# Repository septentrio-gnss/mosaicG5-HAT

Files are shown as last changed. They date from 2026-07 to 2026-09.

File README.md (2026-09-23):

# mosaicG5 HAT

<p align="center">
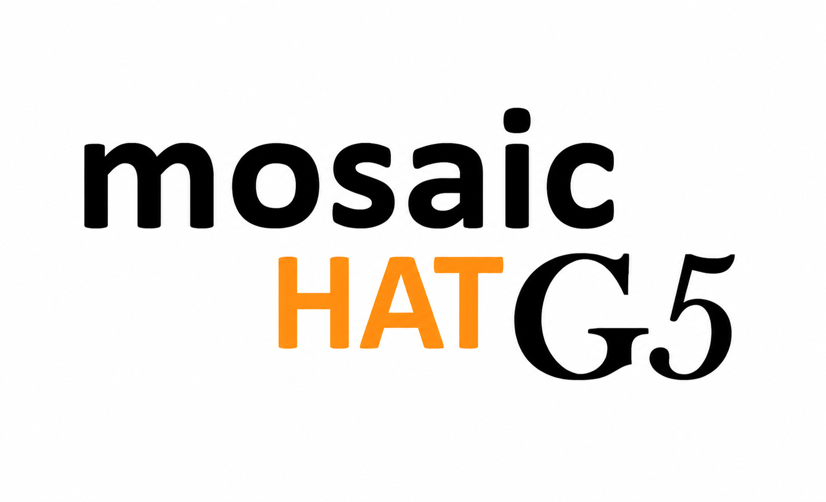
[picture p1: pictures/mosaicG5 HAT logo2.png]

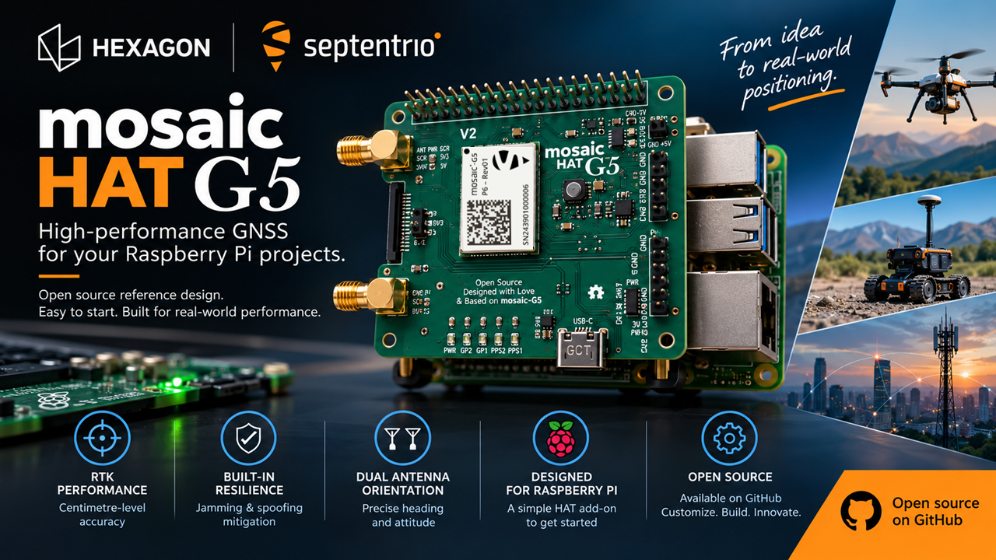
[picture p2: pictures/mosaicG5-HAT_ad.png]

</p>

|mosaicG5 HAT| Open-source GNSS HAT for Raspberry Pi|
|---|---|
|Author|  [laekaz](https://github.com/laekaz)|
|Maintainer| [Septentrio gnss github user](githubuser@septentrio.com)|
|external website| https://github.com/septentrio-gnss/mosaicG5-HAT  |
|License| [CC BY-SA 4.0](https://creativecommons.org/licenses/by-sa/4.0/) and [open-source](https://www.oshwa.org/definition/) |

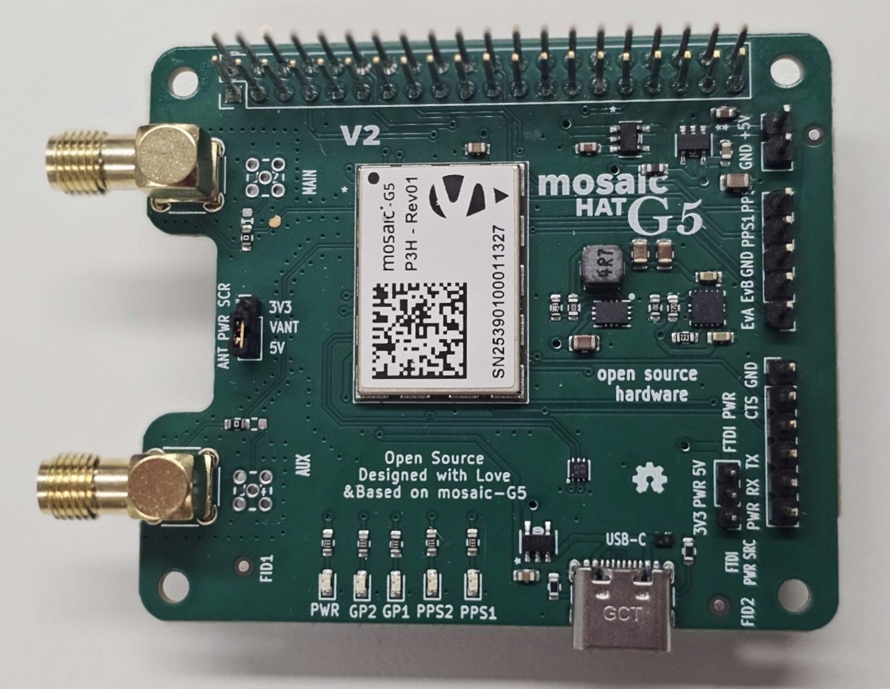
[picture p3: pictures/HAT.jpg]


## Table of Content

* [Introduction to mosaicG5 HAT](#introduction-to-mosaicg5-hat)
  * [What is the mosaicG5 HAT?](#what-is-the-mosaicg5-hat)
  * [A HAT for Raspberry Pi?](#a-hat-for-raspberry-pi)
    * [Robust Mechanical Design](#robust-mechanical-design)
   * [Produce yourself?](#produce-yourself)
    * [Do I need to source special components for producing this board?](#do-i-need-to-source-special-components-for-producing-this-board)
  * [What is a mosaic-G5 module?](#what-is-a-mosaic-g5-module)
    * [Other mosaic-G5 versions](#other-mosaic-g5-versions)
  * [Who is Septentrio?](#who-is-septentrio)
  * [Deliverables](#deliverables)
  * [Is the project open-source?](#is-the-project-open-source)

* [Disclaimer](#disclaimer)

## Introduction to mosaicG5 HAT

### What is the mosaicG5 HAT?
The mosaicG5 HAT is an add-on board that brings high-precision GNSS (GPS) which integrates [mosaic-G5](https://www.septentrio.com/en/products/gnss-receivers/gnss-receiver-modules) Septentrio's GNSS module with basic communications, allowing the system to receive signals from multiple GNSS constellations, such as GPS, Galileo, GLONASS, and BeiDo. 
The goal of the design is to allow easy hardware prototyping and integration of the mosaic-G5 taking advantage of the computer ecosystem provided by the Raspberry pi environment.

The board can also operate as a standalone device when powered through its USB connector or external power input pins.

### Hardware Versions

The mosaicG5 HAT is available in multiple hardware revisions. The latest revision, **V2**, introduces hardware improvements while maintaining compatibility with the software used with V1.

| Version | Description | Software compatibility |
|---|---|---|
| **V1** | Initial production/reference design | Compatible |
| **V2** | Hardware revision with improved hardware design | Compatible |

For detailed information about the changes, advantages, disadvantages, and design decisions of V2, see the [mosaicG5 HAT V2 Hardware Revision](Documentation/mosaicG5%20HAT%20V2%20Hardware%20Revision.md) documentation.

### A HAT for Raspberry Pi?
HAT stands for *Hardware Attached on Top*. It is a type of add-on board specifically designed to sit on top of a Raspberry Pi and connect directly to its 40-pin GPIO header. HATs follow certain standards so they fit neatly, communicate properly, and are powered safely from the Pi.

#### Robust Mechanical Design

Four dedicated mounting holes provide a secure and rigid connection between the Raspberry Pi and the add-on board.

### Produce yourself?
You can use the design files, Bill of Materials from this project and contact your manufacturing company for production. In this project we used JLCPCB for producing the PCB and assembling it. We used JLCPCB because of its competitive pricing and component availability.

##### Do I need to source special components for producing this board?

Yes, Some components are not available through JLCPCB's standard parts library and must be supplied separately. however, if you are assembling the PCB by yourself, all components are available on DigiKey and clearly listed in the project's Bill of Materials. The mosaic GNSS module can be obtained from Digikey or directly from Septentrio. For larger production volumes, we recommend contacting the Septentrio sales team directly at [Septentrio Contact Page](https://www.septentrio.com/en/contact/ask-question)

### What is a mosaic-G5 module?
The mosaic-G5 is a compact GNSS receiver from Septentrio, engineered for high reliability and precise positioning. It integrates the latest multi-band, multi-constellation GNSS technology, providing accurate positions while minimizing power consumption. The receiver can access signals from all major GNSS constellations, including GPS, Galileo, GLONASS, and BeiDou.

#### Other mosaic-G5 versions
Different versions of the mosaic-G5 are available to suit various applications, as summarized below:

| Features | [mosaic-G5 P1](https://www.septentrio.com/en/products/gnss-receivers/gnss-receiver-modules/mosaic-g5-p1) | [mosaic-G5 P3](https://www.septentrio.com/en/products/gnss-receivers/gnss-receiver-modules/mosaic-G5-P3) | [mosaic-G5 P3H](https://www.septentrio.com/en/products/gnss-receivers/gnss-receiver-modules/mosaic-G5-P3H) |[mosaic-G5 P6](https://www.septentrio.com/en/products/gnss-receivers/gnss-receiver-modules/mosaic-G5-P6) | [mosaic-G5 P8](https://www.septentrio.com/en/products/gnss-receivers/gnss-receiver-modules/mosaic-g5-p8) |
|---|---|---|---|---|---|
| Functionality|High-precision positioning |High-precision positioning |Positioning + Heading|Positioning + Heading | Positioning + Heading|
| Use case |Robotics (e.g robotic mowers), GIS devices |UAV, Commercial mowers, Industrial Robotics, Survey, Marine navigation | Marine navigation, Machine control, Autonomous vehicles,  Survey | Autonomous vehicles, Marine navigation, Machine control, Survey | High-end autonomous systems, Robotics, Marine navigation, Survey, Machine control | 
| GNSS bands | Triple-band  | Quad-band | Quad-band |Quad-band |Quad-band  |
| RTK support  | Yes | Yes | Yes |Yes |Yes |
| Dual antenna | No |  No | Yes |Yes |Yes |
| Heading | NO | No | Yes |Yes |Yes |

### Who is Septentrio?
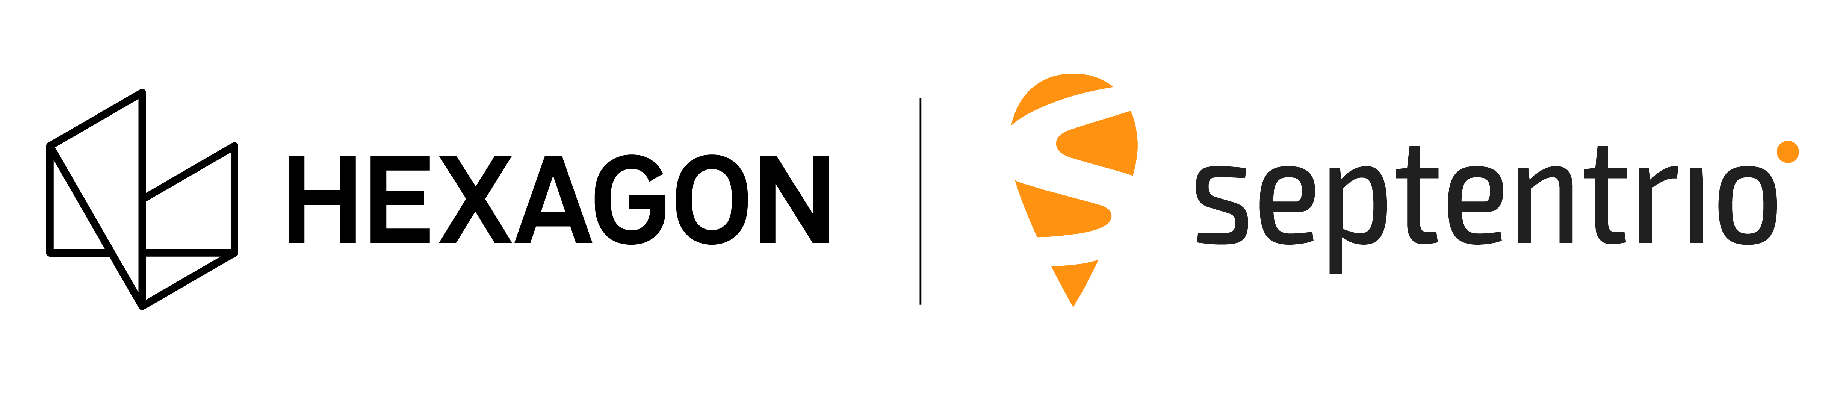
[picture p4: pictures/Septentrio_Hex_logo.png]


Septentrio is a leading company that designs, manufactures and sells high precision and multi-frequency GPS/GNSS receivers for demanding applications. Septentrio products are used in different industries including automotive, marine, construction, rail, machine control, logistics, precision agriculture, geographic information systems (GIS), Unmanned aerial vehicles (UAVs), surveying, mapping and scientific development. Septentrio’s receivers constantly deliver accurate and precise GNSS positioning scalable to centimetre-level and designed to perform perfectly in challenging environments. 

Septentrio's technology offers high accuracy and reliability thanks to advanced GNSS signal-processing algorithms as well as [Advanced interference Monitoring and Mitigation (AIM+)](https://www.septentrio.com/en/learn-more/advanced-positioning-technology/aim-anti-jamming-protection) This protects your application against jamming (RF interference) and spoofing (malicious attacks).

For more information about Septentrio products go to [**https://www.septentrio.com/**](https://web.septentrio.com/GH-SSN-home).

### Deliverables
This project provides the following deliverables for system integrators and hardware designers developing solutions based on Septentrio's mosaic-G5 modules.

|Files |Description |
|---|---|
|  [mosaicG5_RPi_HAT.kicad_pro](./Kicad/mosaicG5%20HAT/V1/mosaicG5_RPi_HAT.kicad_pro) |KiCad project |
| [mosaicG5_RPi_HAT.kicad_pcb](./Kicad/mosaicG5%20HAT/V1/mosaicG5_RPi_HAT.kicad_pcb) | KiCad layout |
|  [mosaicG5_RPi_HAT.kicad_sch](./Kicad/mosaicG5%20HAT/V1/mosaicG5_RPi_HAT.kicad_sch)  |KiCad schematic |
| [mosaic-G5.STEP](./Kicad/mosaci-G5/mosaic-G5.STEP)  |mosaic-G5 3D |
|  [LGA54_MOSAIC-MINI_SEP.kicad_mod](./Kicad/mosaci-G5/LGA54_MOSAIC-MINI_SEP.kicad_mod) |mosaic footprint |
|  [MG5_1.step](./Kicad/mosaicG5%20HAT%203D/MG5_1.step)  |mosaicG5 HAT 3D |
|[BOM](./Kicad/mosaicG5%20HAT/V1/BOM.xlsx) | mosaicG5 HAT Bill of Materials |
### Is the project open-source?
Yes, We made this open-source so you can tinker, adapt, and create. If you are building your own robotics project, a spin-off device, or integrating GNSS into a larger system, this is a great starting point.

Open-source here means:
* All files fully editable
* Freedom to modify, remix, and innovate
* You can sell your version. No -NC limitations
* May require attribution
* Build on our work, push it further, and even make money doing it

More info about licensing can be found here: [CC BY-SA 4.0](https://creativecommons.org/licenses/by-sa/4.0/) and [open-source](https://www.oshwa.org/definition/)

## Disclaimer
This project is **offered as-is**. The main interfaces have been tested, but the design has not been fully checked or approved by the author or Septentrio. You are responsible for how you use it in your own projects. For guidance on working with Septentrio’s GNSS mosaic-G5 modules, we suggest reaching out to Septentrio directly.

Support website: https://www.septentrio.com/en/support
### Documentation Sections

This project provides two main documentation sections:

- **[mosaicG5 HAT User Documentation](Documentation/mosaicG5%20HAT%20User%20Documentation.md)**  
  Contains information for users on how to install, configure, and use the mosaicG5 HAT.

- **[mosaicG5 HAT Design Documentation](Documentation/mosaicG5%20HAT%20Design%20Documentation.md)**  
  Intended for hardware designers who want to understand, customize, or modify the reference design of the mosaicG5 HAT.
- **[mosaicG5 HAT V2 Hardware Revision](Documentation/mosaicG5%20HAT%20V2%20Hardware%20Revision.md)**

  Hardware revision with updated hardware design

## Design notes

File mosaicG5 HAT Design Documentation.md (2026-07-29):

# mosaicG5 HAT Design Documentation

## Table of Content

* [Design Overview](#design-overview)
* [mosaic-G5 Pinout](#mosaic-g5-pinout)
* [Power Sources](#power-sources)
* [Antennas](#antennas)
    * [Antenna Connectors](#antenna-connectors)
    * [First Antenna](#first-antenna)
    * [Second Antenna](#second-antenna)
* [Raspberry Pi Serial](#raspberry-pi-serial)
* [Reset Input](#reset-input)
* [USB-C](#usb-c)
* [Events and PPSO](#events-and-ppso)
* [FTDI](#ftdi)
* [LEDs](#leds)
* [Clock Frequency Reference](#clock-frequency-reference)
* [Further Improvements](#further-improvements)

This section describes the design principles and architecture of the mosaicG5 HAT in depth.

## Design Overview

The mosaicG5 HAT is a four-layer Printed Circuit Board (PCB) designed to mount directly onto a Raspberry Pi. The top and bottom layers are used for both signal and power routing. The first internal layer serves as a ground (GND) plane, while the second internal layer is primarily used as a 3.3 V power plane, with limited routing for additional connections where required.

With the exception of the Raspberry Pi female header connector, all components are mounted on the top side of the board. The design uses Surface-Mount Devices (SMDs) throughout, except for the external connectors.

The mosaicG5 HAT was developed using [KiCad](https://www.kicad.org/download/), an open-source Electronic Design Automation (EDA) suite. In addition to its schematic capture and PCB layout capabilities, KiCad includes an integrated 3D viewer that provides a realistic representation of the assembled board.

The schematic diagram is shown below. For improved readability and access to complete design details, refer to the PDF version of the [schematic](/Kicad/mosaicG5%20HAT/mosaicG5_RPi_HAT.kicad_sch).

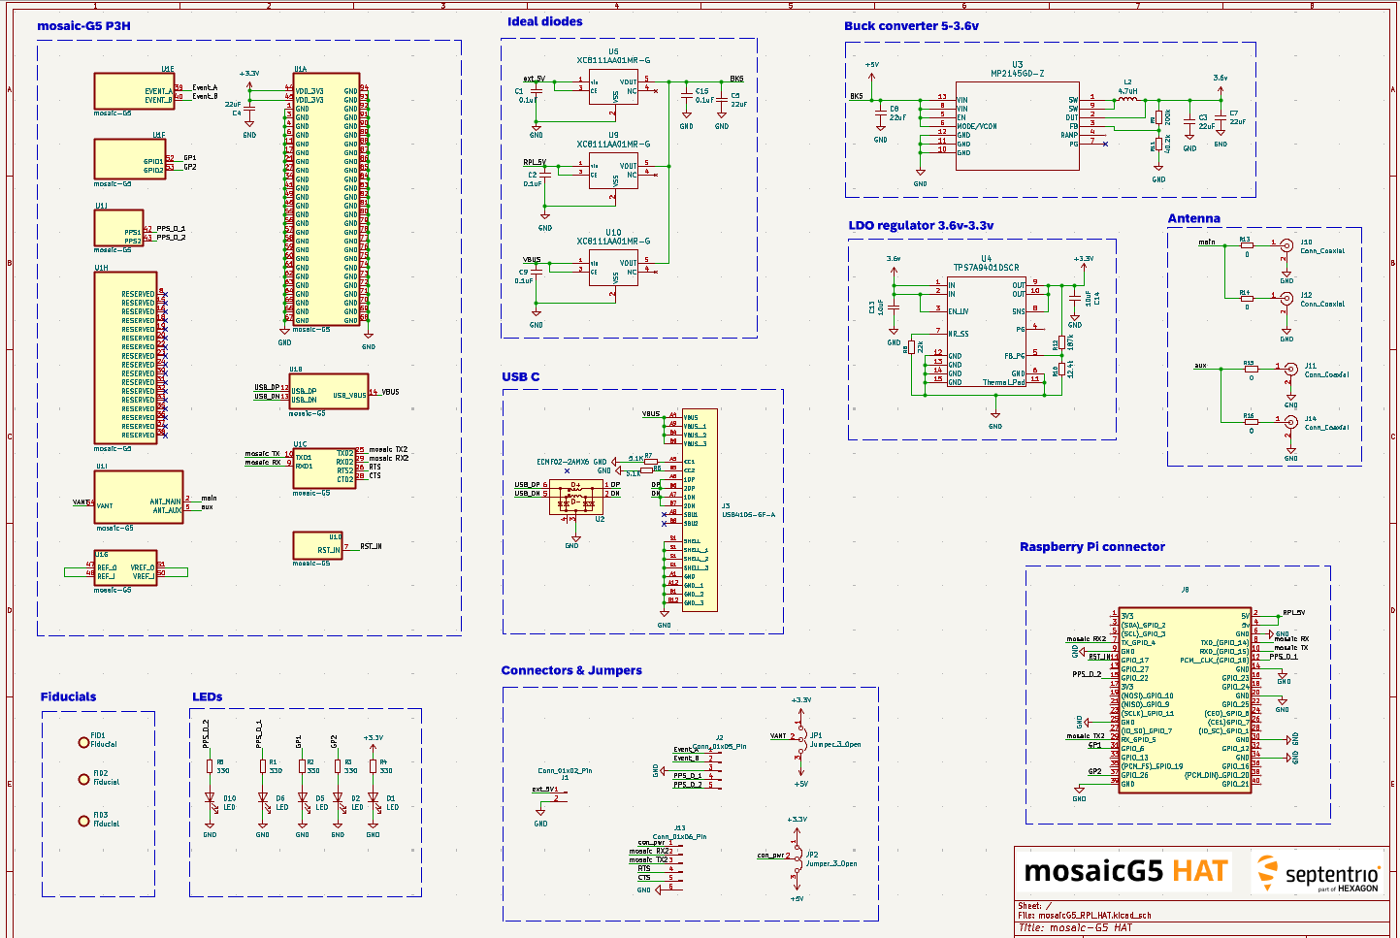
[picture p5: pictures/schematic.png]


The board layout without the copper pour.

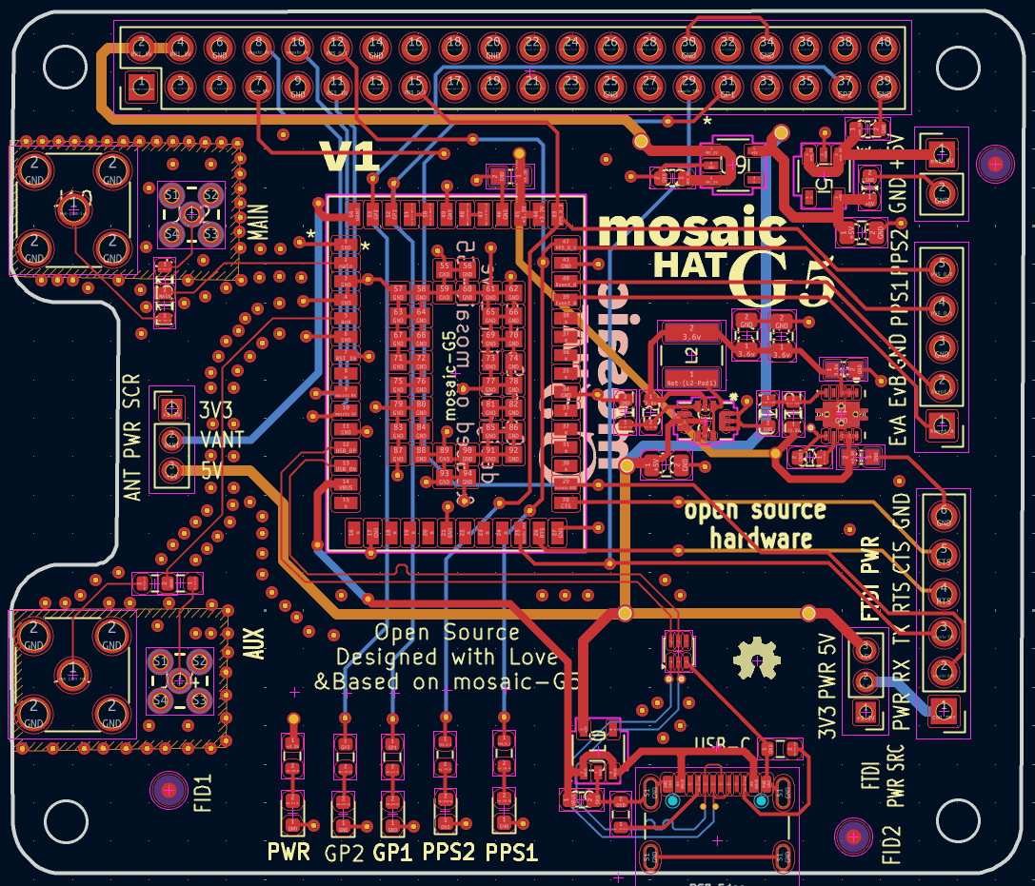
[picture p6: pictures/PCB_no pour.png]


The board layout with the copper pour

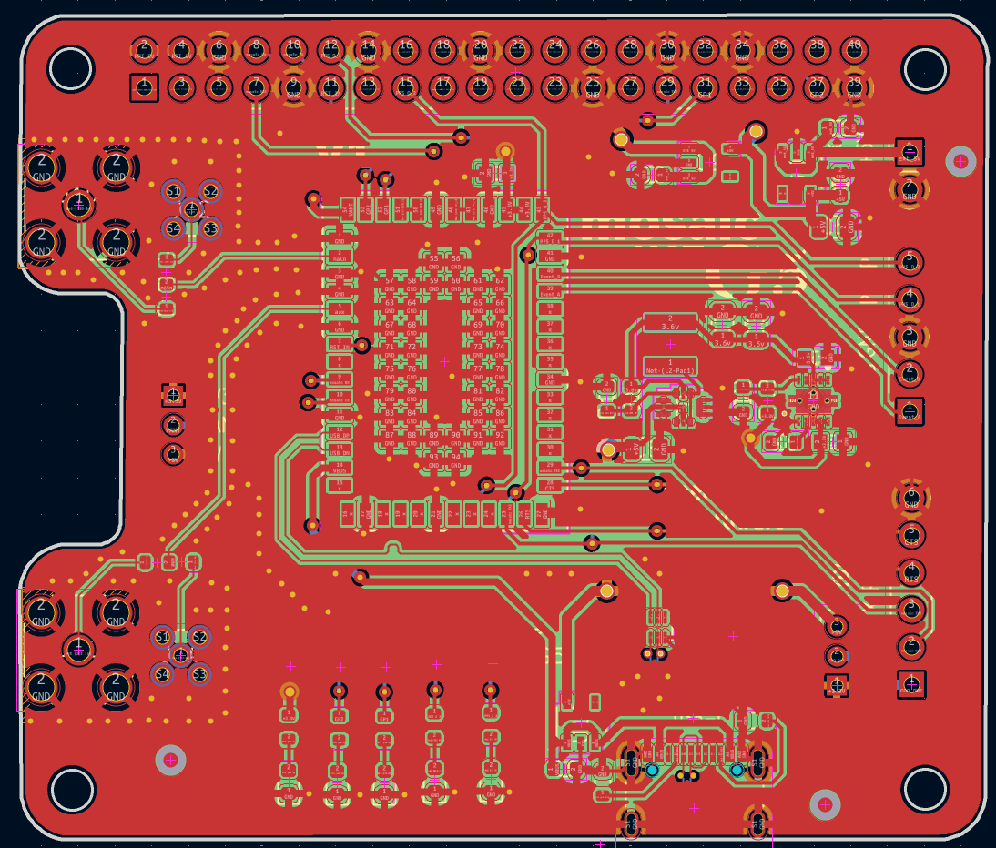
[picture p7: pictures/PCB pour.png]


Layout layer descriptions:

|Layer|Description|
|---|---|
|Layer 1| Red traces, copper pour connected to GND |
|Layer 2| Solid GND plane |
|Layer 3| Orange traces, copper pour connected to 3.3 V |
|Layer 4| Blue traces, copper pour connected to GND|

A top 3D view of the mosaicG5 HAT, featuring main electronic components.

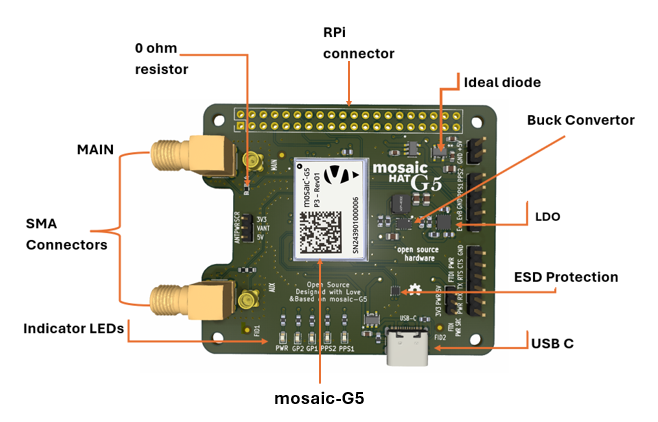
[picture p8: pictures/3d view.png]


## mosaic-G5 Pinout
The Septentrio mosaic-G5 is the core of the mosaicG5 HAT board. It is a 22.8 x 16.4 mm compact GNSS module of 94 pins with a weight of 2.2 g. Complete information on mosaic-G5 connections can be found in the [Hardware Manual](https://www.septentrio.com/en/products/gnss-receivers/gnss-receiver-modules/mosaic-G5-P3H).

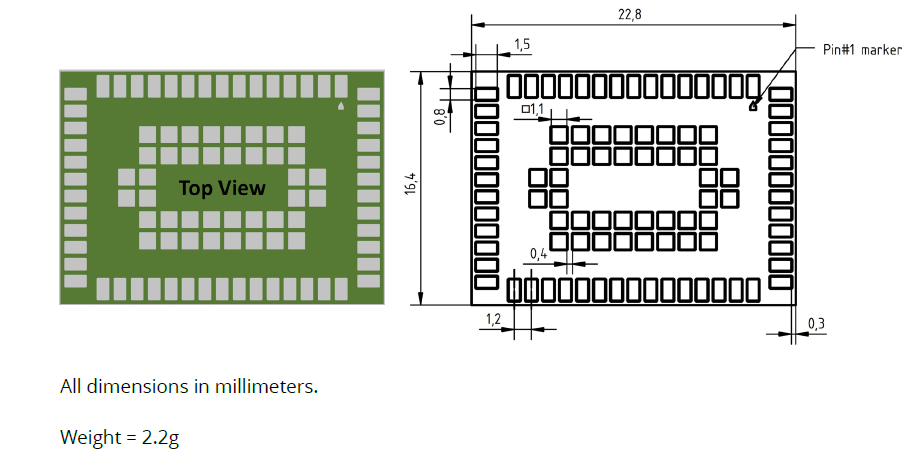
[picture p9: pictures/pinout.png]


The symbol, footprint and 3D model of mosaic-G5 can be found [here](https://app.ultralibrarian.com/details/536b89de-4b22-11f0-b69d-024899f9dfe1/Septentrio/MOSAIC-G5-P3)

## power sources

The mosaicG5 HAT has 3 options for powering the board; Raspberry Pi, USB-C and external power pin headers. The mosaic-G5 module itself runs on 3.3V, thus a buck converter(MP2145GD-Z) is used to regulate the voltage from 5V to 3.6V and an LDO voltage regulator is used to filter the switching noise from the buck converter and to regulate the voltage from 3.7 to 3.3volts(TPS7A9401DSCR). Raspberry Pi and USB-C already provide 5V.

 **NOTE:** When using the external power connector, only 5 V should be applied.

 **WARNING:** Applying voltages higher than 5 V to the external power input or higher than the specified voltage to **VANT** may damage the module

The ideal diodes (**XC8111AA01MR-G**) are used to ensure one-way current flow. Decoupling capacitors (1 µF) are used according to the datasheet. The following figure shows the power section of the schematic.

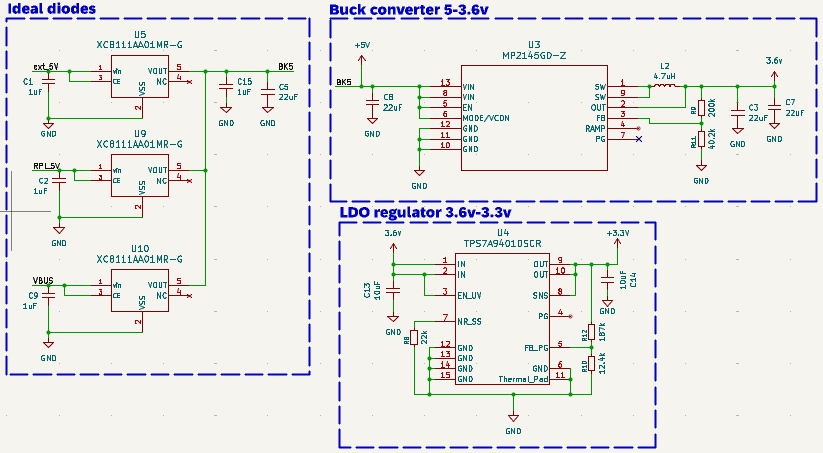
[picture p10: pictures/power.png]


In the figure above:
1. Buck converter(MP2145GD-Z).
2. Voltage regulator (TPS7A9401DSCR).
3. Raspberry Pi power source (5V pins).
4. External power source headers.
5. Micro USB power source.

## Antennas 
The mosaic-G5 P3H is a dual-antenna while the mosaic-G5 P3 is a single-antenna both of these modules are compatible with the PCB board however, when connecting the mosaic-G5 P3 you only connect the main antenna connector and leave the auxiliary unconnected. Both the antenna pins are not ESD-protected or biased in the schematics because all is done inside the module. 

The following figure shows the antenna section of the schematic.

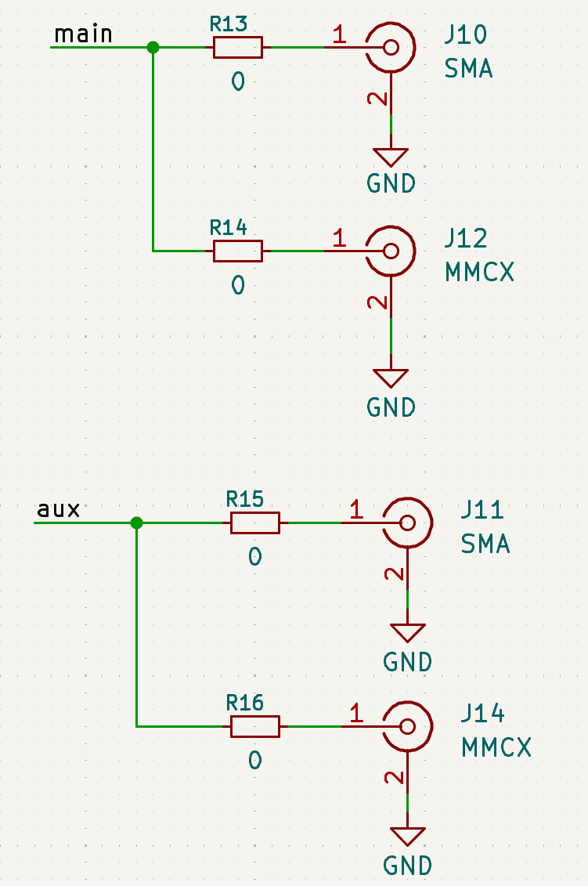
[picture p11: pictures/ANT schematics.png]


### Antenna Connectors

The PCB includes footprints for both SMA and U.FL antenna connectors. When assembling the PCB you can choose the type of connector you are going to choose. You do that by assembling one of the resistor to select either antenna connector.mosaicG5 HAT user can choose between 3.3V and 5V supply for the antenna voltage(VANT) using 2.00 mm header jumpers.

### First Antenna

The first SMA antenna J10 is directly connected to a 0 ohm resistor and the first MMCX antenna J12 is also connected to a 0 ohm resistor and they are both connected to the main mosaic-G5 pin.
The DC voltage of the main antenna connection is supplied from the mosaic-G5's VANT pin.

The input impedance of the RF line is 50 Ohms. Thus, antenna trace should have a characteristic impedance (Zo) of 50 Ohms. To determine the proper impedance for the antenna traces for RF signal routing, calculations were performed with the [JLCPCB Impedance Calculator](https://jlcpcb.com/pcb-impedance-calculator)(recommended if you are using JLCPCB as manufacturer) or can use freeware [Saturn PCB toolkit](https://saturnpcb.com/pcb_toolkit). The trace parameters used in the calculation were based on the specifications of the selected PCB manufacturer. Calculations determined that a trace width of 0.1425 mm would provide an impedance of 50Ω to the RF antenna traces.

Having right characteristic impedance ensures reduced signal reflections in the opposite direction thus higher quality of signals. For uniform lines, characteristic impedance is dependent on trace length.

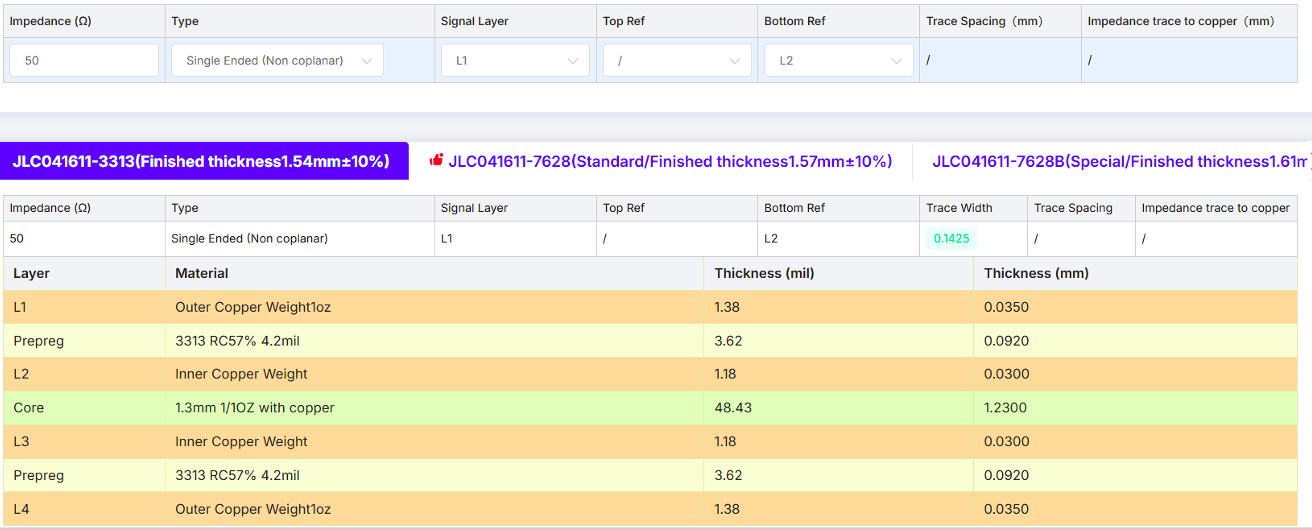
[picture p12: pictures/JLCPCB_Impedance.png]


It is also important to stitch vias every few millimeters around the RF line for good ground coherence. Ground stitching vias help to protect line from interference.

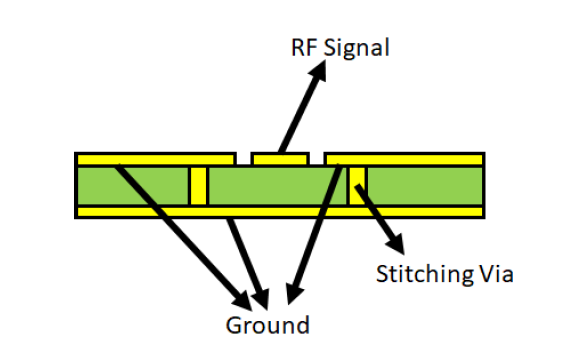
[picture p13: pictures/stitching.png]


For more details on antennas and interference please refer to mosaic-G5's [Hardware Manual](https://www.septentrio.com/en/products/gnss-receivers?f%5B0%5D=type%3A604).

### second antenna

The second antenna is similar to the first antenna except when using a single antenna module like the mosaic-G5 P3, you do not need to assemble the the second antenna connector. 

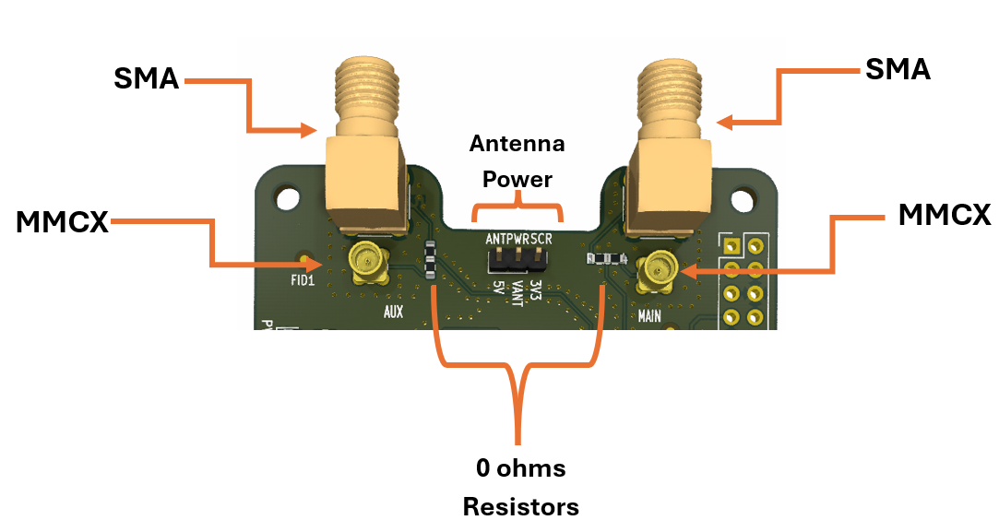
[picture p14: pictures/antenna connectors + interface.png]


## Raspberry pi serial

Serial communication between the mosaic-G5 and the Raspberry Pi is implemented by connecting UART1 and UART2 connections of mosaic-G5 to Raspberry Pi UART pins: TX (GPIO_14, GPIO_5) and RX (GPIO_15, GPIO_4). GPIO_14 and GPIO_5 are pin 8 and pin 29 respectively on the GPIO header whereas GPIO_15 and GPIO_4 are pin 10 and pin 7 respectively. The mosaic-G5's TX is connected to the Raspberry Pi's RX while RX is connected to Raspberry Pi's TX for both UARTs.

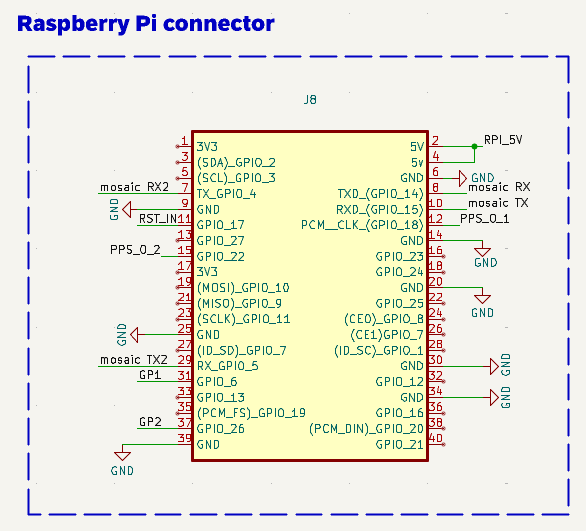
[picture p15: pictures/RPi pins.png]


## Reset Input
The RST_IN pin of mosaic-G5 is directly connected to RPi GPIO 17 (Pin 11 in physical header). Refer to [Reset mosaic](#reset-mosaic-G5) in user documentation for more details.

## USB-C
To use mosaic-G5 as a USB device, the following pins of the module should be connected to a USB-C connector:



A common mode filter with ESD protection for USB 2.0 (ECMF02-2AMX6) is used with USB_DP (D+) and USB_DN (D-) for protection. The filter suppresses electromagnetic interference (EMI) on high-speed differential USB lines.

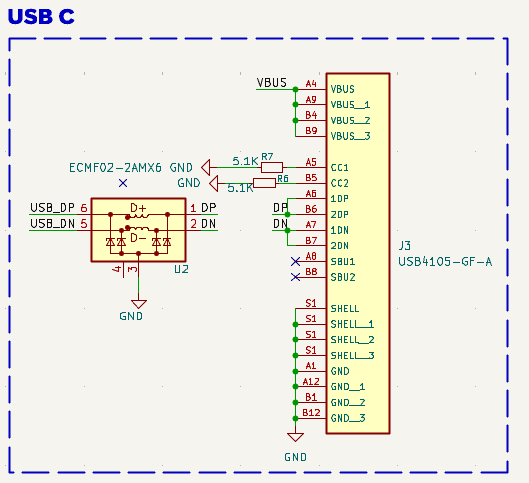
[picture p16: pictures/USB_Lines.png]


As USB uses a differential pair for data transmission, differential pair impedance (Zdifferential) should be tuned to avoid reflections. Zdifferential needs to be around 90 Ohms. The same [JLCPCB impedance calculator](https://jlcpcb.com/pcb-impedance-calculator) was used to determine the dimensions of the differential signal pair that will carry the USB signals. 

The parameters used for this calculation were the same as those used for the RF antenna traces: the materials, thickness of copper finish, and number of layers of the PCB manufacturer that was selected. The results of this calculation determined that a width of 0.1468 mm would provide the necessary impedance of 90 Ω to the differential signal pair. 

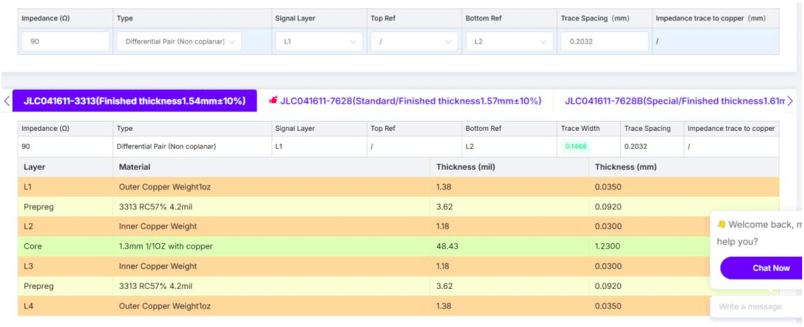
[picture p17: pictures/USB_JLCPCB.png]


The following figure hights USB parts highlighted. GND vias were stitched around the USB connector and lines to ensure good ground coherence.

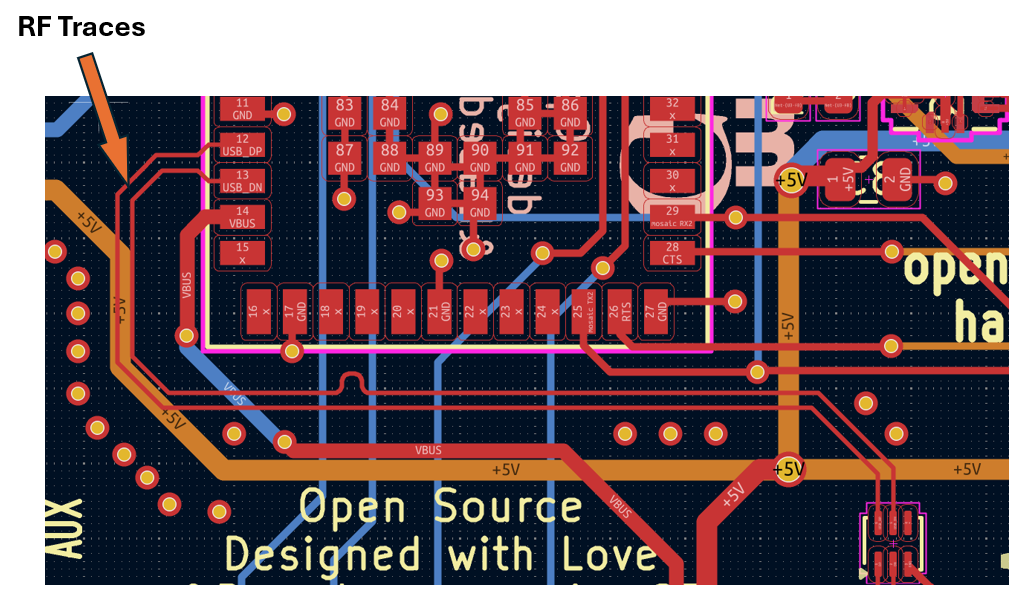
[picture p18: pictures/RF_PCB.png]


* USB-C connector (USB4105-GF-A).
* Common mode filter.
* USB D+/D- lines.
* VBUS.

## FTDI
Second serial interface to mosaic-G5 (UART2) is exposed through 2.54 mm pin headers. The FTDI connection allows communication with other devices through serial (e.g. HC-06 Bluetooth module).

If the external device needs power supply from mosaicG5 HAT, like HC-06, VCC pin of FTDI could be used. 5V or 3.3V could be provided by moving the FTDI PWR SRC jumpers.

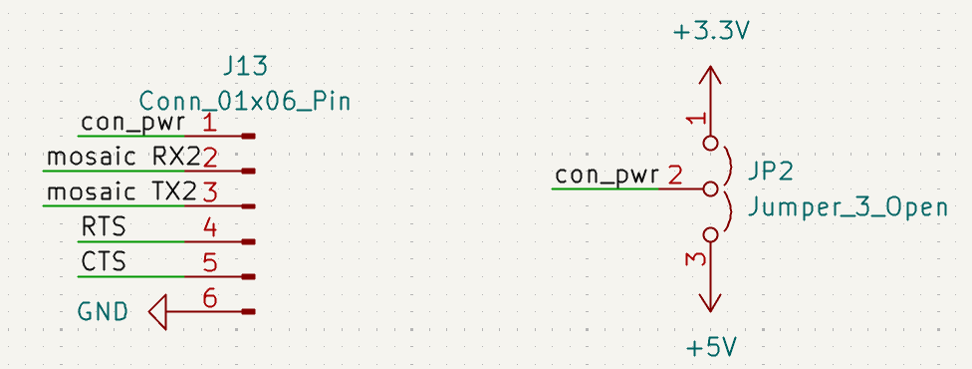
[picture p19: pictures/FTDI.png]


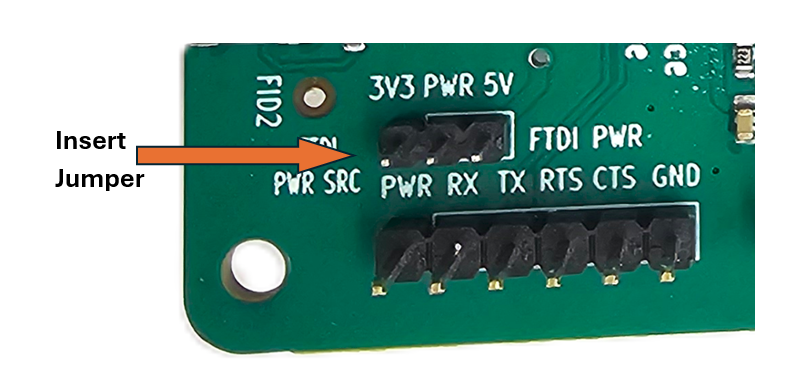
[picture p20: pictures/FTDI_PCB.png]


## LEDs

mosaicG5 HAT has five blue indicator LEDs.

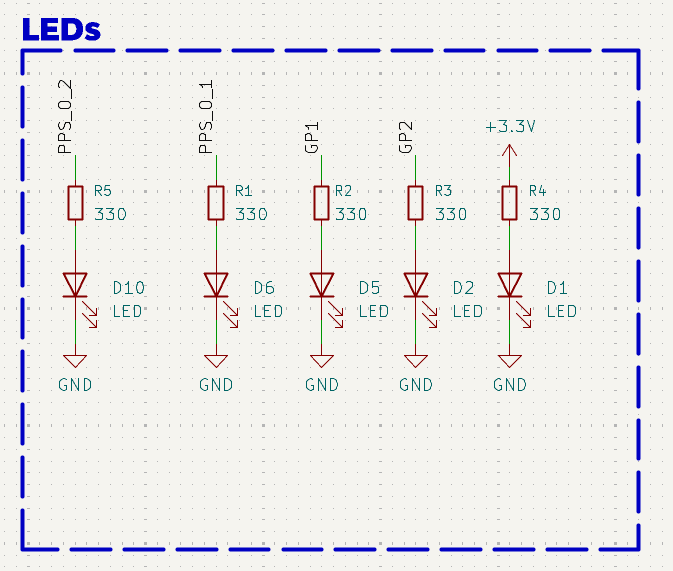
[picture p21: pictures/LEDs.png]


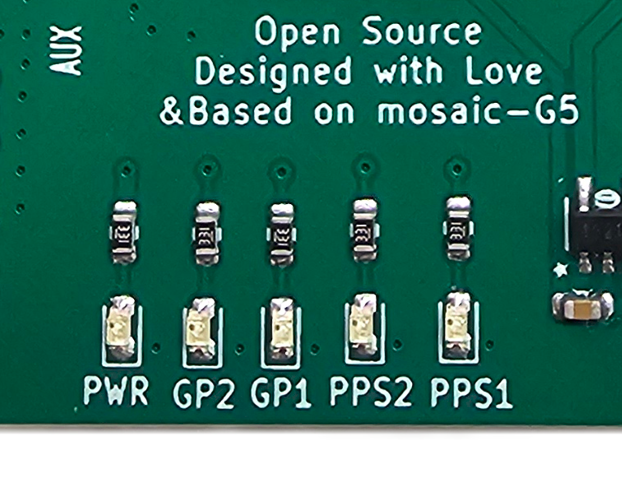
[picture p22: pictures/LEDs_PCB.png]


## Clock Frequency Reference
mosaic-G5 module embeds an internal Temperature Compensated Crystal Oscillator (TCXO) for frequency reference. The module can either use its internal TCXO frequency reference or an external frequency reference. In mosaicG5 HAT's case, internal reference is used.

Following are Hardware Manual instructions for using internal TCXO.



Layout connections for REF and VREF_I.

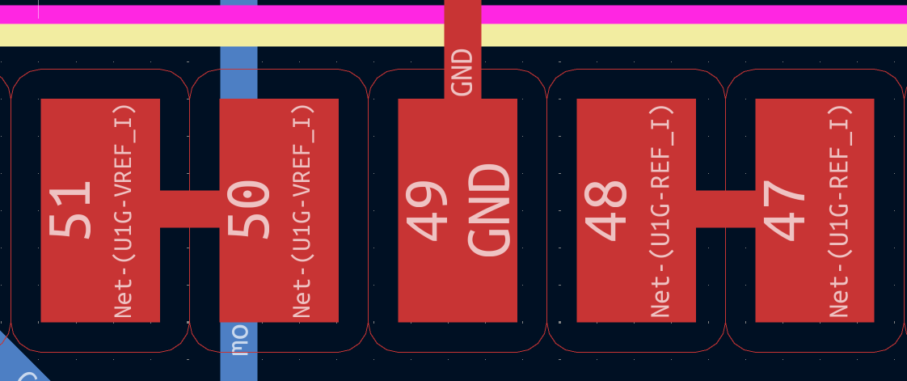
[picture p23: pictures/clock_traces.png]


## Further improvements

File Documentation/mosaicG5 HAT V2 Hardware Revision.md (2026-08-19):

# mosaicG5 HAT V2 Hardware Revision

This document describes the V2 hardware revision of the mosaicG5 HAT and the changes made compared with the original V1 design.

V2 is a hardware-only revision. No changes were made to the software, communication protocol, or user operation of the board.

## Table of Content

## Design Files

| File | Description |
|---|---|
| [mosaicG5_RPi_HAT.kicad_pro](../Kicad/mosaicG5%20HAT/V2/mosaicG5_RPi_HAT.kicad_pro) | V2 KiCad project |
| [mosaicG5_RPi_HAT.kicad_sch](../Kicad/mosaicG5%20HAT/V2/mosaicG5_RPi_HAT.kicad_sch) | V2  KiCad schematic |
| [mosaicG5_RPi_HAT.kicad_pcb](../Kicad/mosaicG5%20HAT/V2/mosaicG5_RPi_HAT.kicad_pcb) | V2  KiCad  PCB layout |
| [BOM](../Kicad/mosaicG5%20HAT/V2/BOM%20P3H_V2.xlsx) | mosaicG5 HAT V2 Bill of Materials |

## V2 Hardware Changes

| Change | V2 modification | Purpose |
|---|---|---|
| **ESD protection** | Added an ESD protection diode on the VBUS input | Protects the board against electrostatic discharge through the USB power connection |
| **Power filtering** | Added **L1 ferrite bead** between the ideal-diode stage and buck converter |Helps filter noise before it reaches the buck converter|
| **FTDI interface** | Rearranged the FTDI pins to follow the standard pin arrangement | Makes the interface more convenient and compatible with standard FTDI connections |
| **Buck converter output** | Increased from **3.6 V to 3.7 V** | Provides additional voltage headroom for the 3.3 V LDO |
| **LDO input margin** | Changed from **3.6 V - 3.3 V** to **3.7 V - 3.3 V** | Increases the voltage margin available to the LDO to maintain a stable 3.3 V output |

### FTDI Interface
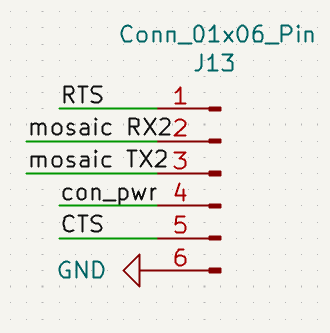
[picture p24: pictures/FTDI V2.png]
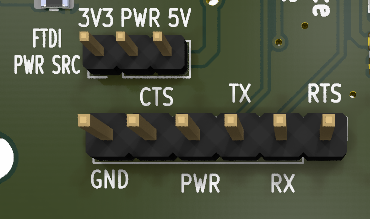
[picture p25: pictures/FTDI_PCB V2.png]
 

The FTDI pin arrangement was changed to follow the standard FTDI pinout, making it easier to connect compatible FTDI cables and adapters while maintaining the same UART2 functionality described in the V1 FTDI section.

### What Remains Unchanged?

No changes were made to:

- mosaic-G5 module
- Raspberry Pi interface
- UART functionality
- PPS functionality
- USB data interface
- Antenna connections
- LED functionality
- Clock reference

These parts of the design remain as described in the V1 documentation.

### Does V2 still work with the existing user documentation?

Yes, V2 remains compatible with the existing mosaicG5 HAT V1 user documentation, with no software changes required, as the communication interfaces and board functionality remain unchanged.

## Revision Summary

| Revision | Description |
|---|---|
| V1 | Initial hardware design |
| V2 | Hardware revision with improved design |

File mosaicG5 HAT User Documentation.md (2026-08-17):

# mosaicG5 HAT user documentation
## Table of Content

* [mosaicG5 HAT User Documentation](#mosaicg5-hat-user-documentation)
  * [mosaicG5 HAT Manufacturing and Assembly](#mosaicg5-hat-manufacturing-and-assembly)
    * [Elements to provide when manufacturing the board](#elements-to-provide-when-manufacturing-the-board)
    * [Ordering mosaic module](#ordering-mosaic-module)
  * [General Interfaces of mosaicHAT](#general-interfaces-of-mosaichat)
  * [Connecting to Raspberry Pi](#connecting-to-raspberry-pi)
    * [Preparing Raspberry Pi](#preparing-raspberry-pi)
  * [GNSS Antenna](#gnss-antenna)
    * [Heading](#heading)
  * [USB Communication](#usb-communication)
  * [Serial Communication](#serial-communication)
  * [FTDI Connector](#ftdi-connector)
  * [LED Indicators](#led-indicators)
  * [Reset mosaic-G5](#reset-mosaic-g5)
  * [PPS Output](#pps-output)
  * [Events](#events)
  * [Python Script](#python-script)

## mosaicG5 HAT Manufacturing and Assembly

This project includes all the files required to manufacture the mosaicG5 HAT, including the reference design, PCB layout, and Bill of Materials (BOM). You can use these files with your preferred PCB manufacturer. For this project, we used [JLCPCB](https://jlcpcb.com/) for both PCB fabrication and assembly due to their competitive pricing and fast production times.

### Elements to provide when manufacturing the board
When you manufacture your board they will ask you for the following parts:

For the PCB only:
* The PCB design, you will need to export gerber and drill files 

For assembly:

* Bill of Materials (BOM), the list of components used in the project with their reference designators. For this project check [BOM](./BOM.xlsx).
* Component Placement List (CPL), this file contains the exact position of each component on the board (X,Y and rotation). CPL is exported from KiCad however, you need to check with the manufacturer services to ensure the right placement for components.

### Ordering mosaic module
You can order the mosaic-G5 from Digi-Key, or you can contact Septentrio at www.septentrio.com for purchasing inquiries or other mosaic models.

| mosaic-G5 versions | Septentrio | Digi-Key part_number|
|---|---|---|
| mosaic-G5 P1 |[Septentrio_G5-P1](https://www.septentrio.com/en/products/gnss-receivers/gnss-receiver-modules/mosaic-g5-p1) | - |
| mosaic-G5 P3 | [Septentrio_G5-P3](https://www.septentrio.com/en/products/gnss-receivers/gnss-receiver-modules/mosaic-G5-P3) | [410501](https://www.digikey.com/en/products/detail/septentrio-inc/410501/28527327) |
| mosaic-G5 P3H |[Septentrio_G5-P3H](https://www.septentrio.com/en/products/gnss-receivers/gnss-receiver-modules/mosaic-G5-P3H) | [410502](https://www.digikey.com/en/products/detail/septentrio-inc/410502/28527213) |
| mosaic-G5 P6 |[Septentrio_G5-P6](https://www.septentrio.com/en/products/gnss-receivers/gnss-receiver-modules/mosaic-G5-P6) | [410503]() |
| mosaic-G5 P8 |[Septentrio_G5-P8](https://www.septentrio.com/en/products/gnss-receivers/gnss-receiver-modules/mosaic-g5-p8) | [410610]() |

## General interfaces of mosaicHAT
The board exposes the following interfaces:

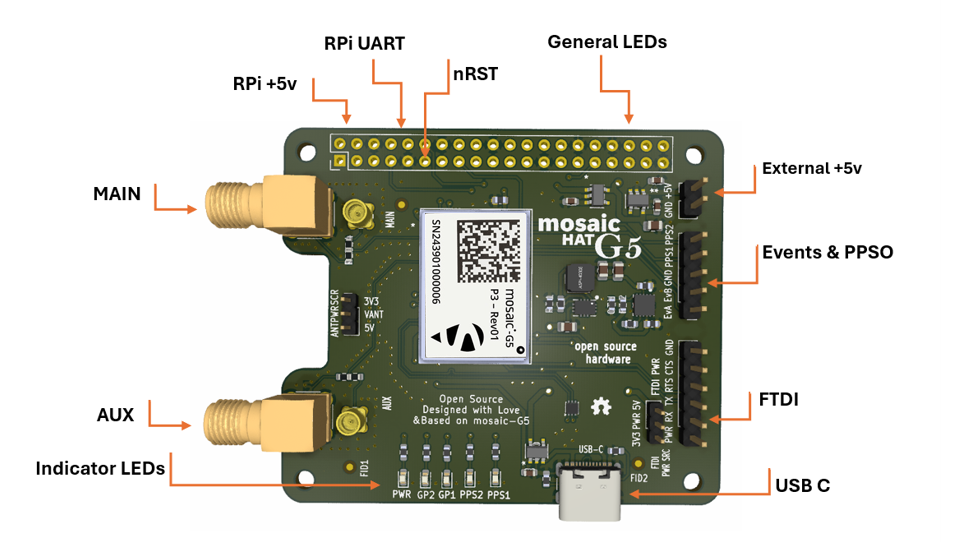
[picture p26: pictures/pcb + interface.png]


## Connecting to Raspberry Pi
mosaicG5 HAT can be easily attached to Raspberry Pi as shown here:

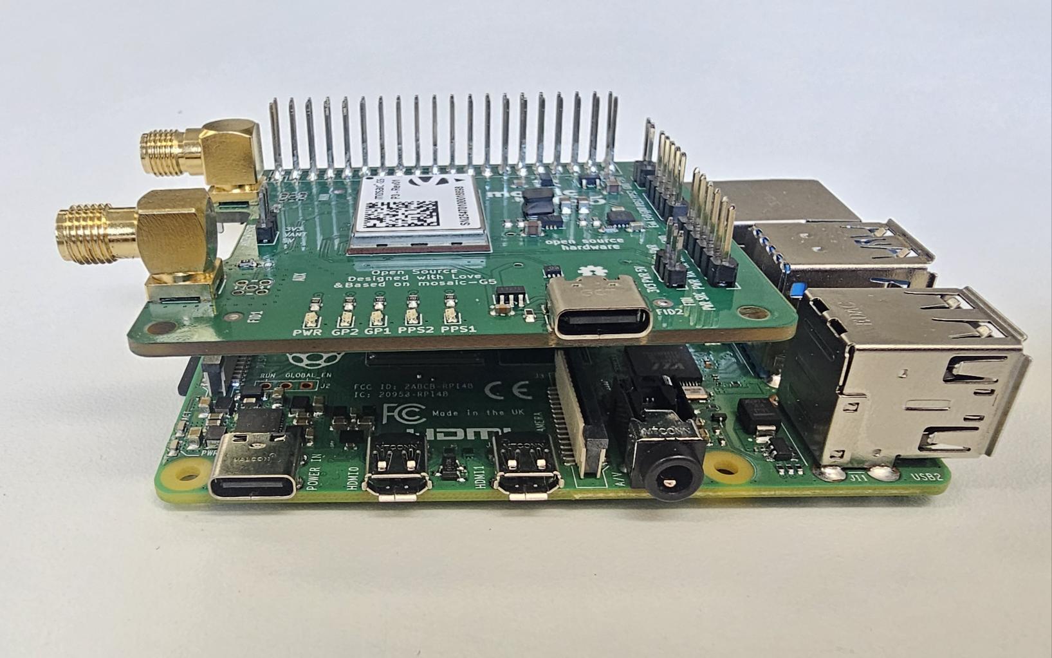
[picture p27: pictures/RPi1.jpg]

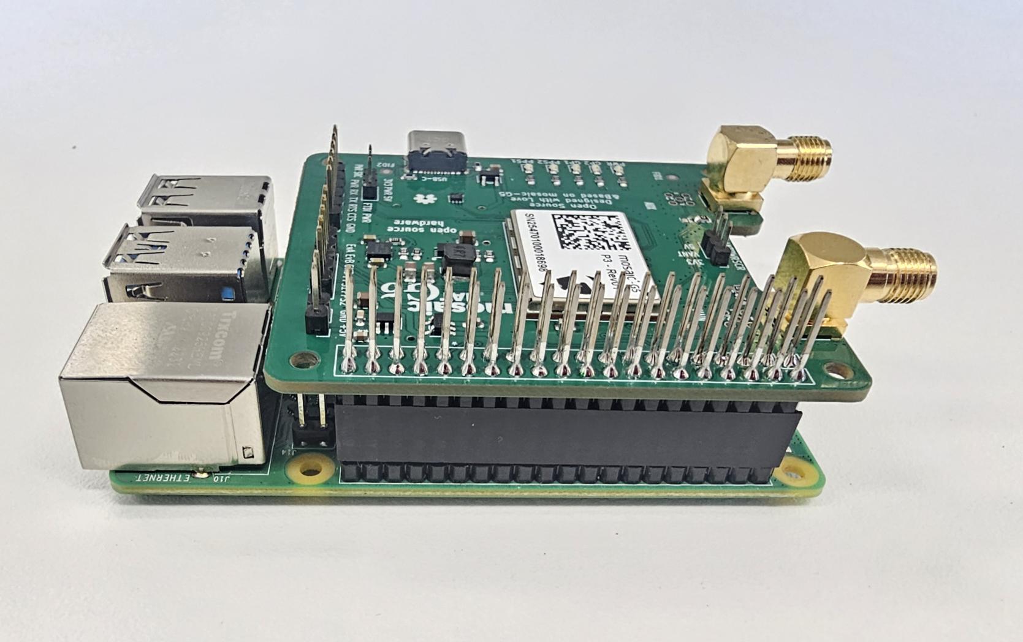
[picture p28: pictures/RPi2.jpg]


### Preparing Raspberry Pi
To enable communication between mosaicG5 HAT and Raspberry Pi (RPi), you should make sure required serial communication settings are configured.

Raspberry Pi OS
* To enable RPi serial communication, go to terminal and run:

```sudo raspi-config```

* Select **Interfacing Options**, then from the menu select Serial Port.
You will get the question:
would you like a login shell to be accessible over serial?
select **No**. Another prompt will ask:
would you like serial port hardware to be enabled?
select **Yes**.

* Reboot the Raspberry Pi for the changes to take effect.

```sudo reboot```

* After reboot check UART devices

```ls -l /dev/serial* ```

The output should be similar to:

```/dev/serial0 -> ttyAMA0```

```/dev/serial1 -> ttyS0```

On the RPi 4 
serial0 maps to GPIO 14 and 15 which are connected to UART1 of the mosaic-G5. 

To communicate with UART1, use:

```/dev/serial0```

To enable RPi's UART, go to /boot/config.txt and set enable_uart=1 at the end of the file. This could be done directly on SD card or using:

```sudo nano /boot/config.txt```

when using the second UART connected from the mosaic-G5 module t the RPi 

add the line ```dtoverlay=uart3``` to the file to enable UART3 connected to the UART2 of the mosaic-G5 module

* Reboot the Raspberry Pi for the changes to take effect.

```sudo reboot```

* After reboot check UART devices

```ls -l /dev/ttyAMA* ```

The output should be similar to:

```/dev/ttyAMA3```

### GNSS Antenna

To take full advantage of the multi-band and multi-constellation capabilities of the mosaicG5 HAT, it is recommended to use a high-quality multi-band GNSS antenna.

Several manufacturers offer suitable GNSS antennas, including Maxtena and Tallysman. You can also contact Septentrio for guidance on selecting an antenna that best fits your application.

GNSS antennas are available in different form factors and performance levels, each designed for specific use cases such as robotics, precision agriculture, surveying, or industrial machinery. While larger antennas often provide better performance due to improved antenna design and larger ground planes, antenna quality and internal element design are equally important factors. Selecting the right antenna for your application will have a significant impact on positioning accuracy and reliability.

For testing the board we used Tallysman antenna:

<img src="pictures/antenna.jpg" width="30%">

**NOTE**: The VANT (Antenna voltage) pad of mosaic-G5 module is directly connected to the external +5V pin. The internal bias control circuit detects overcurrent
conditions (>150mA) and protects the module in case of short circuit. According to mosaic-G5 hardware manual, VANT accepts 3V to 5.5V power supply.

When using the external power supply, make sure it is not more than 5V. Supplying higher voltages to VANT could **DAMAGE** the module.

#### Single/Dual Antenna Mode

The receiver can operate in either **single-antenna** or **dual-antenna** mode. Changing the frontend mode only takes effect after a reboot.

**Single-antenna mode**

Run:

```
setFrontendMode, SingleAnt
```
to configure the receiver for single-antenna mode at the next reboot.

Then save the configuration:

```
exeCopyConfigFile, Current, Boot
```

Finally, reboot the receiver:

```
exeResetReceiver, Hard, none
```

**Dual-antenna mode**
Run:

```
setFrontendMode, DualAnt
```
to configure the receiver for dual-antenna mode at the next reboot.

Then save the configuration:

```
exeCopyConfigFile, Current, Boot
```
Finally, reboot the receiver:

```
exeResetReceiver, Hard, none
```
P3H, P6 and P8 can run both in single or dual mode deppending on how you configure it. connect both the antenner connectors when using dual mode. 

#### Heading

You can use mosaic-G5 P3H for heading but **it's necessary to connect the two antenna connectors.** 

RxTools can be used to monitor the heading.

<img src="pictures/Heading.png" width="50%">

### USB communication

The mosaicG5 HAT via USB provides 2 USB serial ports that can be used with [Septentrio's RxTools](https://www.septentrio.com/en/products/gps-gnss-receiver-software/rxtools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).

Septentrio's RxTools is a Software which can be used to communicate to the mosaic-G5 HAT and can be downloaded free of charge from the [Septentrio support site](https://www.septentrio.com/en/products/gps-gnss-receiver-software/rxtools#resources). Once you have downloaded it you can use Septentrio's RxControl and Data Link which can communicate with the receiver over a serial-port connection: select Serial Connection option when opening the connection to the receiver.

<img src="pictures/rxcontrol.png" width="50%">

**NOTE:** That currently there's no RxTools release for RPi (ARM architecture). Thus, RxTools should be used on a regular PC.

### Serial communication
A simple way to communicate with the mosaic-G5 receiver is to connect one of the UART, it offers 2 UARTs connections.

* Both UART connections are  connected to the Raspberry-Pi for easie integration.

### FTDI-connector
An extra serial port is made available and can be used as an FTDI. FTDI can also be used with some Bluetooth devices. There is a large variety of FTDI devices which can help in communicating with the mosaic G5 HAT.

* The UART2 connection of the mosaic is exposed via pin header on the board. This can be usuable to connect an FTDI converter(eg. serial to Bluetooth or TLL to RS232 converter)

<img src="pictures/FTDI_TTL.png" width="50%">

TTL to USB connection

<img src="pictures/TLL_connection.png" width="50%">

Serial connection of mosaic G5 HAT could be tested using PuTTY

Default COM-Port settings are:
|Parameter     |Value         |
|--------------|--------------|
|baud rate     | 115200     |   
|data bits | 8   |
|parity    |no    |
|stop bits | 1    |
|flow control | none|

<img src="pictures/putty.png" width="50%">

Can use comment ```sno, Stream1, COM2, GGA, sec1``` to output GGA data on the UART2

### LED indicators
The follwing LEDs are defined on the mosaicHAT

|**LED**  |**Description**   |
|-------|-------|
|PWR    | Board State (ON/OFF)  |
|GL1    | Conected to mosaic G5 and RPi GPIO1  |
|GL2 | Connected to mosaic-G5 and RPi GPIO26   |
|PPS2 | Pulse Per Second  |
|PPS1 | Pulse Per Second  |

<img src="pictures/LED_indicators.png" width="50%">

PPSO clock could be tuned using **setPPSParameters** command. While GPLEDs default mode is PVTLED, it could be configured to work in different modes (PVTLED, DIFFCORLED and TRACKLED) using setLEDMode command. Refer to the Hardware Manual for blinking behaviour of each mode. Both General Purpose LEDs (GL1 and GL2) could be directly controlled by Raspberry Pi GPIO.

Just for illustration, the following python script runs GL1 and GL2  together with the GNSS code. When there is no GNSS data GL1 will turn on and when there is GNSS data GL2 will turn on.

Find the code [here](/Python%20code/MG5_RPI_LED_code.py)

### Reset mosaic-G5

mosaic-G5 could be forced to reset from Raspberry Pi. The RST_IN pin of mosaic-G5 is directly connected to RPi GPIO 17 (Pin 11 in physical header).

The RST_IN pin is active negative, which means mosaic will be in RESET mode when RST_IN is low (GND). The pin is internally debounced (pull-up) so if pin is left unconnected (floating) the module will not enter RESET mode.

Initially, the RPi GPIO pins are set to INPUT mode. As the RPi input line have high impedance, RST_IN will be floating. This means mosaicHAT board could run without issues initially even if GPIO 17 is not set to HIGH (while kept in input mode). However, it is not recommended to rely on the GPIO initial state. Users should drive HIGH to GPIO 17 for the stability of their applications.

To reset module, a LOW pulse, not shorter than 1 microsecond, should be driven to GPIO 17.

### PPS output

PPS signals are used for precise timekeeping and time measurement. One increasingly common use is in time synchronization with other sensors (e.g. Lidars or IMUs).

The receiver is able to generate an x-pulse-per-second (xPPS) signal aligned with GPS, Galileo, GLONASS system time, UTC, or with the internal receiver time (RxClock). 

Polarity, frequency and pulse width of PPSO could be configured by **setPPSParameters** command.

<img src="pictures/Eve&PPSO.png" width="50%">

By default, **PPSO2 is disabled**. It can be enabled and configured in **RxControl**:.

<img src="pictures/PPS2.PNG" width="50%">
<img src="pictures/PPS2_.png" width="25%">

Both PPS Output operate at 3.3 V logic levels. PPSO1 and PPSO2 are directly connected to an indicator LED. 

More information on the definition of PPS output or on how to configure the PPS parameters can be found in the mosaic-G5 reference guide. You can download this one from [Septentrio site](https://www.septentrio.com/en/products/gnss-receivers/gnss-receiver-modules/mosaic-G5-P3H).

### Events
EVENTs could be tested directly on mosaicG5 HAT board by connecting PPS Output to one of the EVENTs pins. Note that this works with a single wire because they share the same GND. Here PPSO_1 is connected to EVENTB, with PPS interval set to 1 sec.

<img src="pictures/event_console.png" width="40%">
<img src="pictures/event.png" width="30%">

To monitor Events you could use Rxcontrol, clicking on the expert console. once you have connected an output to the event pin you will see the data being recieved on the pin.

**Note:** The **EVENT** inputs use **3.3 V logic levels**. Applying higher voltages may damage the receiver.

For more information about the EVENT input functionality, see the **mosaic-G5 Reference Guide**, available from the [Septentrio website](https://www.septentrio.com/en/products/gnss-receivers/gnss-receiver-modules/mosaic-G5-P3H).

### Python script

Find the full code [here](/Python%20code/MG5_RPI_code.py)
```
import serial   # Library used for UART / serial communication
import time     # Library used for implementing timing delays

# Establish UART serial connection to the GNSS receiver
serial_port = serial.Serial('/dev/serial0', 115200)

# /dev/serial0 refers to the primary Raspberry Pi UART interface
# 115200 baud is the default communication speed of the mosaic-G5 receiver

# If using USB serial communication instead of UART, the device may appear as:
# /dev/ttyACM0, /dev/ttyACM1, etc.
# Available serial devices can be checked using:
# dmesg | grep tty

# If permission errors occur when accessing USB serial ports, run:
# sudo chmod 666 /dev/ttyACM0

time.sleep(1) # delay for serial connection time to be initialise properly

serial_port.write(b'SSSSSSSSSSSSS\n') # Send multiple 'S' characters to place the mosaic-G5 into command mode

time.sleep(0.1) # Short delay to ensure the command is processed

# Enable continuous NMEA GGA message streaming once per second on COM1
# For USB communication, replace COM1 with USB1 or USB2
serial_port.write(b'sno, Stream1, COM1, GGA, sec1\n')

time.sleep(0.1) # delay for reading incoming serial data

while True:
  
    nmea_data_bytes = serial_port.readline()          # Read one complete line of incoming serial data from the receiver   
    nmea_sentence = str(nmea_data_bytes.decode())      # Decode received byte data into a UTF-8 string    
    nmea_sentence = nmea_sentence.rstrip()            # Remove newline and whitespace characters

    # Check if the received NMEA sentence is a GNGGA position message
    if (nmea_sentence.startswith('$GNGGA')):
       
        nmea_fields = [element.strip() for element in nmea_sentence.split(',')]      #separated NMEA fields with a comma into a list
       
        quality_indicator = int(nmea_fields[6])                                      #Get the NMEA quality indicator field
       
        if quality_indicator==0:                    # Quality indicator value of 0 means no valid GNSS position fix

            print("No GPS Fix Available!")

        else:
            utc_time = float(nmea_fields[1])                 # Parse UTC time field from the NMEA GGA message
            latitude = float(nmea_fields[2])*0.01            # Get latitude value in NMEA format
            latitude_direction = nmea_fields[3]             # Get latitude hemisphere indicator (N or S)
            longitude = float(nmea_fields[4])*0.01           # Get longitude value in NMEA format
            longitude_direction = nmea_fields[5]             # Get longitude hemisphere indicator (E or W)
            altitude = float(nmea_fields[9])                  # Get altitude above mean sea level           
            altitude_unit = nmea_fields[10]                  # Get altitude unit, typically metres (M)

            # Display parsed GNSS positioning information
            print('UTC Time: ' + str(utc_time))
            print(' Latitude: ' + str(latitude) + latitude_direction)
            print(' Longitude: ' + str(longitude) + longitude_direction)
            print(' Height: ' + str(altitude) + altitude_unit)  

        # Delay before processing the next incoming message
        time.sleep(0.1)
    else:
        continue         # Ignore non-GGA NMEA messages and continue listening
serial_port.close()     # Close serial connection when the program terminates

```

When you connect to the second UART change **COM1** to **COM2** o

```serial_port.write(b'sno, Stream1, COM2, GGA, sec1\n')```
and the serial port

```serial_port = serial.Serial('/dev/ttyAMA3', 115200)```

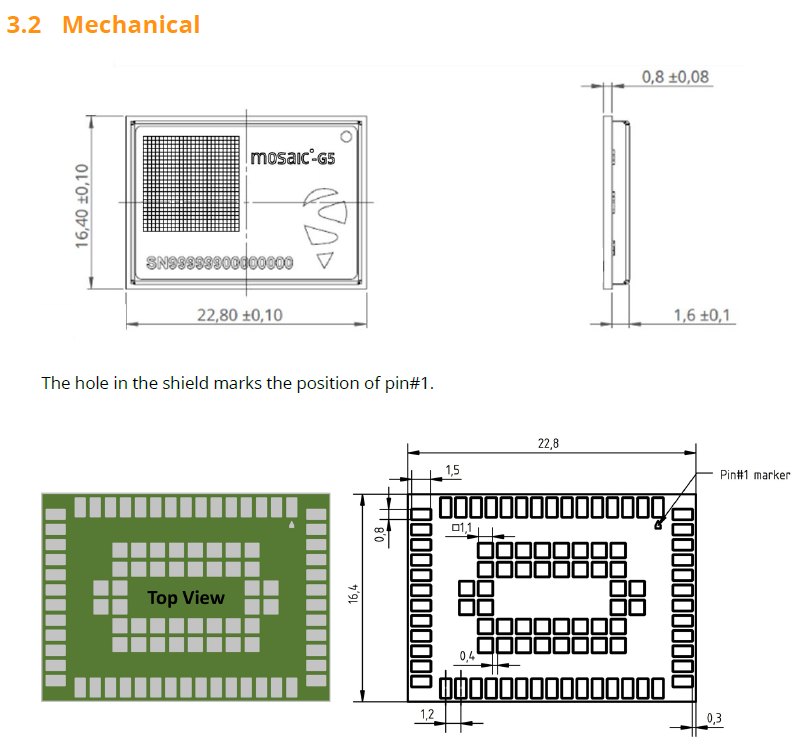
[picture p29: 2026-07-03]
pictures/mechanical.png

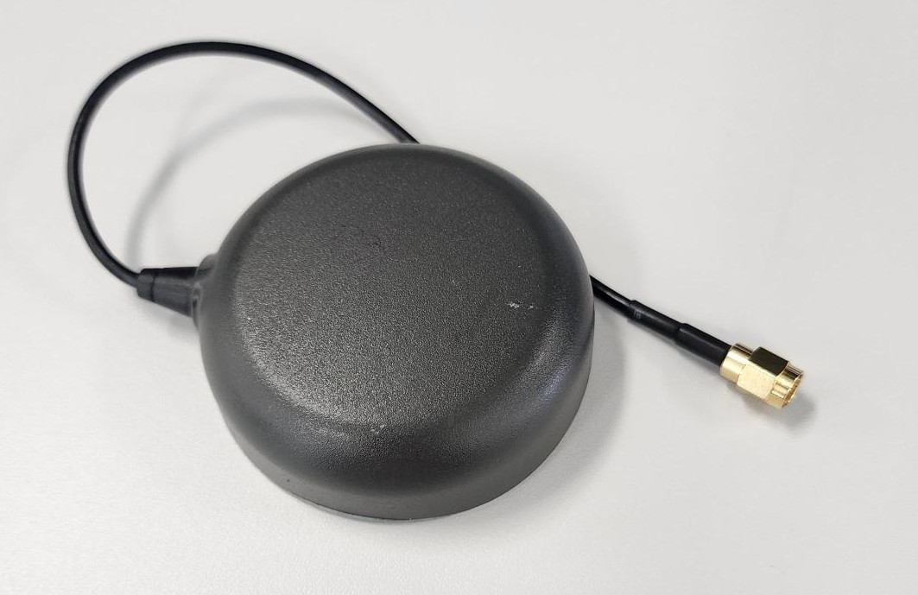
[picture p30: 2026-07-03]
pictures/antenna.jpg

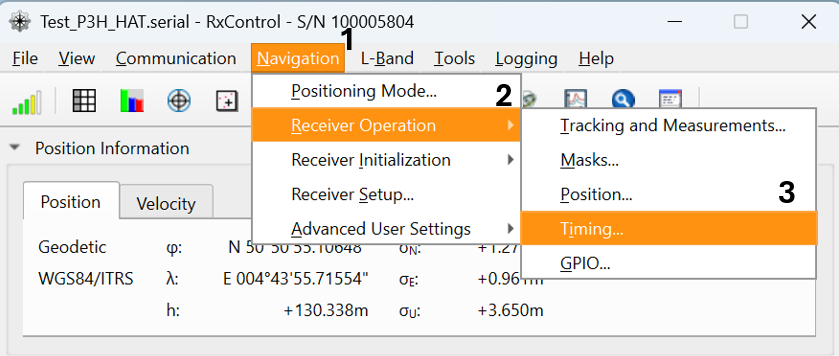
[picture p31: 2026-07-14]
pictures/PPS2.PNG

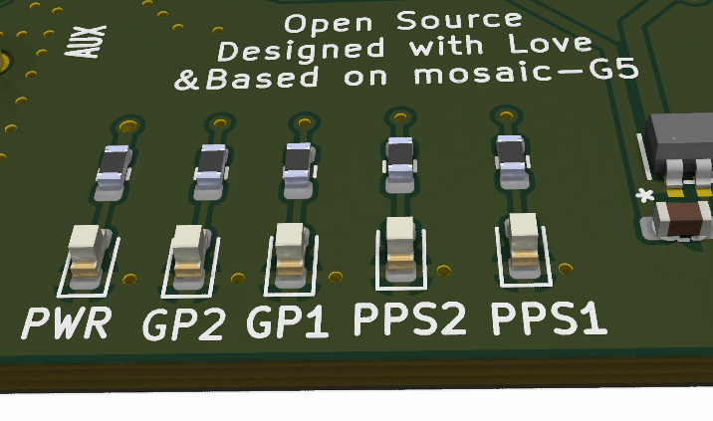
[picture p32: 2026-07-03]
pictures/LED_indicators.png

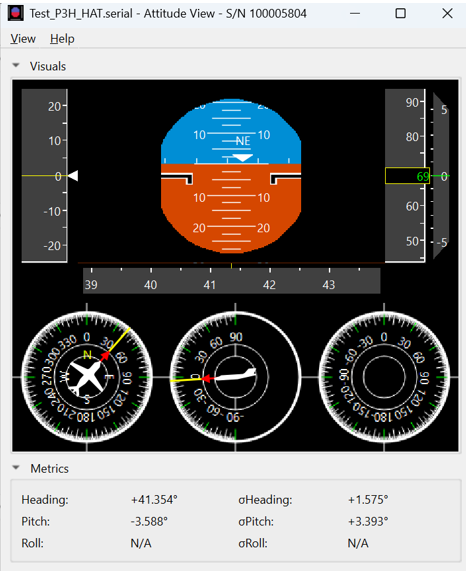
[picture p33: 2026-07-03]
pictures/Heading.png

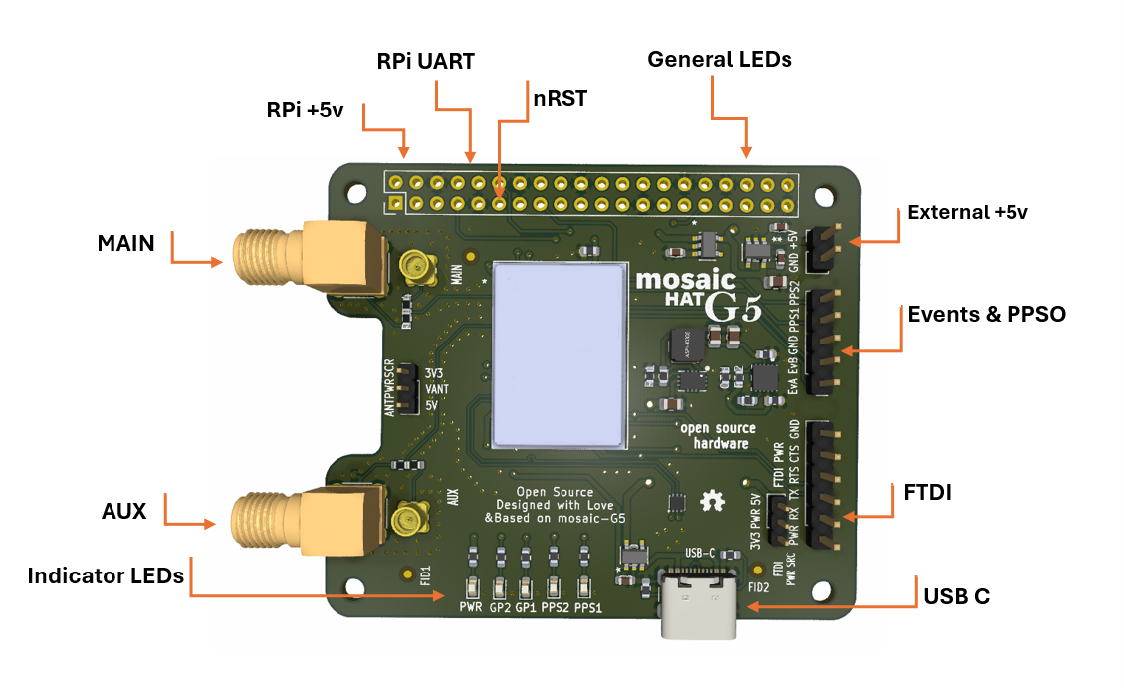
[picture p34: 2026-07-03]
pictures/pcb + interface2.png

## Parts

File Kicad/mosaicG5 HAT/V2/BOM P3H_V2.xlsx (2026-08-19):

Designator | Value | Package | Part | Quantity
C1 | 1µF | C_0603_1608Metric | C106248 | 1
C13 | 10µF | CAPC1608X90 | C22399626 | 1
C14 | 10µF | CAPC1608X90 | C22399626 | 1
C15 | 1µF | C_0603_1608Metric | C106248 | 1
C2 | 1µF | C_0603_1608Metric | C106248 | 1
C3 | 22µF | C_0805_2012Metric | C23692981 | 1
C4 | 22µF | CAPC1608X90 | C15500 | 1
C5 | 22µF | C_0805_2012Metric | C23692981 | 1
C7 | 22µF | C_0805_2012Metric | C23692981 | 1
C8 | 22µF | C_0805_2012Metric | C23692981 | 1
C9 | 1µF | C_0603_1608Metric | C106248 | 1
D1 | LED | LED_0603_1608Metric | C440514 | 1
D10 | LED | LED_0603_1608Metric | C440514 | 1
D2 | LED | LED_0603_1608Metric | C440514 | 1
D3 | ESDA7P120_1U1M | ESD_ESDA7P120-1U1M | C2969802 | 1
D5 | LED | LED_0603_1608Metric | C440514 | 1
D6 | LED | LED_0603_1608Metric | C440514 | 1
J1 | Conn_01x02_Pin | C2905434 | C2905434 | 1
J10 | Conn_Coaxial SMA | C3174435 | C3174435 | 1
J11 | Conn_Coaxial SMA | C3174435 | C3174435 | 1
J13 | Conn_01x06_Pin | C5444523 | C5444523 | 1
J2 | Conn_01x05_Pin | C6461551 | C6461551 | 1
J3 | USB4105-GF-A | USB_C_Receptacle_GCT_USB4105-xx-A_16P_TopMnt_Horizontal | C3020560 | 1
J8 | 2x20_2.54mm_pitch | C35165 | C35165 | 1
JP1 | Jumper_3_Open | C22438286 | C22438286 | 1
JP2 | Jumper_3_Open | C22438286 | C22438286 | 1
L2 | 4.7µH | IND_ASPI-4030S-4R7M-T | C3224051 | 1
L1 | IND_BLM18_0603_MUR _ 33ohms | BLM18PG330SN1D | C88984
R1 | 330Ω | 0603_(1608metric) | C23138 | 1
R10 | 12.4kΩ | 0603_(1608metric) | C22865 | 1
R11 | 39kΩ | 0603_(1608metric) | C163424 | 1
R12 | 187kΩ | 0603_(1608metric) | C22896 | 1
R13 | 0Ω | 0603_(1608metric) | C177335 | 1
R15 | 0Ω | 0603_(1608metric) | C177335 | 1
R2 | 330Ω | 0603_(1608metric) | C23138 | 1
R3 | 330Ω | 0603_(1608metric) | C23138 | 1
R4 | 330Ω | 0603_(1608metric) | C23138 | 1
R5 | 330Ω | 0603_(1608metric) | C23138 | 1
R6 | 5.1kΩ | 0603_(1608metric) | C123727 | 1
R7 | 5.1kΩ | 0603_(1608metric) | C123727 | 1
R8 | 22kΩ | 0603_(1608metric) | C881373 | 1
R9 | 200kΩ | 0603_(1608metric) | C332260 | 1
U1 | mosaic-G5 P3H | LGA54_MOSAIC-MINI_SEP | LGA54_MOSAIC-MINI_SEP | 1
U10 | XC8111AA01MR-G | SOT-25_TOR | C3235548 | 1
U2 | ECMF02-2AMX6 | ST_UQFN-6L_1.5x1.7mm_P0.5mm | C2651144 | 1
U3 | MP2145GD-Z | QFN-12_MP2145_MNP | C132200 | 1
U4 | TPS7A9401DSCR | DSC0010J-MFG | C5220127 | 1
U5 | XC8111AA01MR-G | SOT-25_TOR | C3235548 | 1
U9 | XC8111AA01MR-G | SOT-25_TOR | C3235548 | 1

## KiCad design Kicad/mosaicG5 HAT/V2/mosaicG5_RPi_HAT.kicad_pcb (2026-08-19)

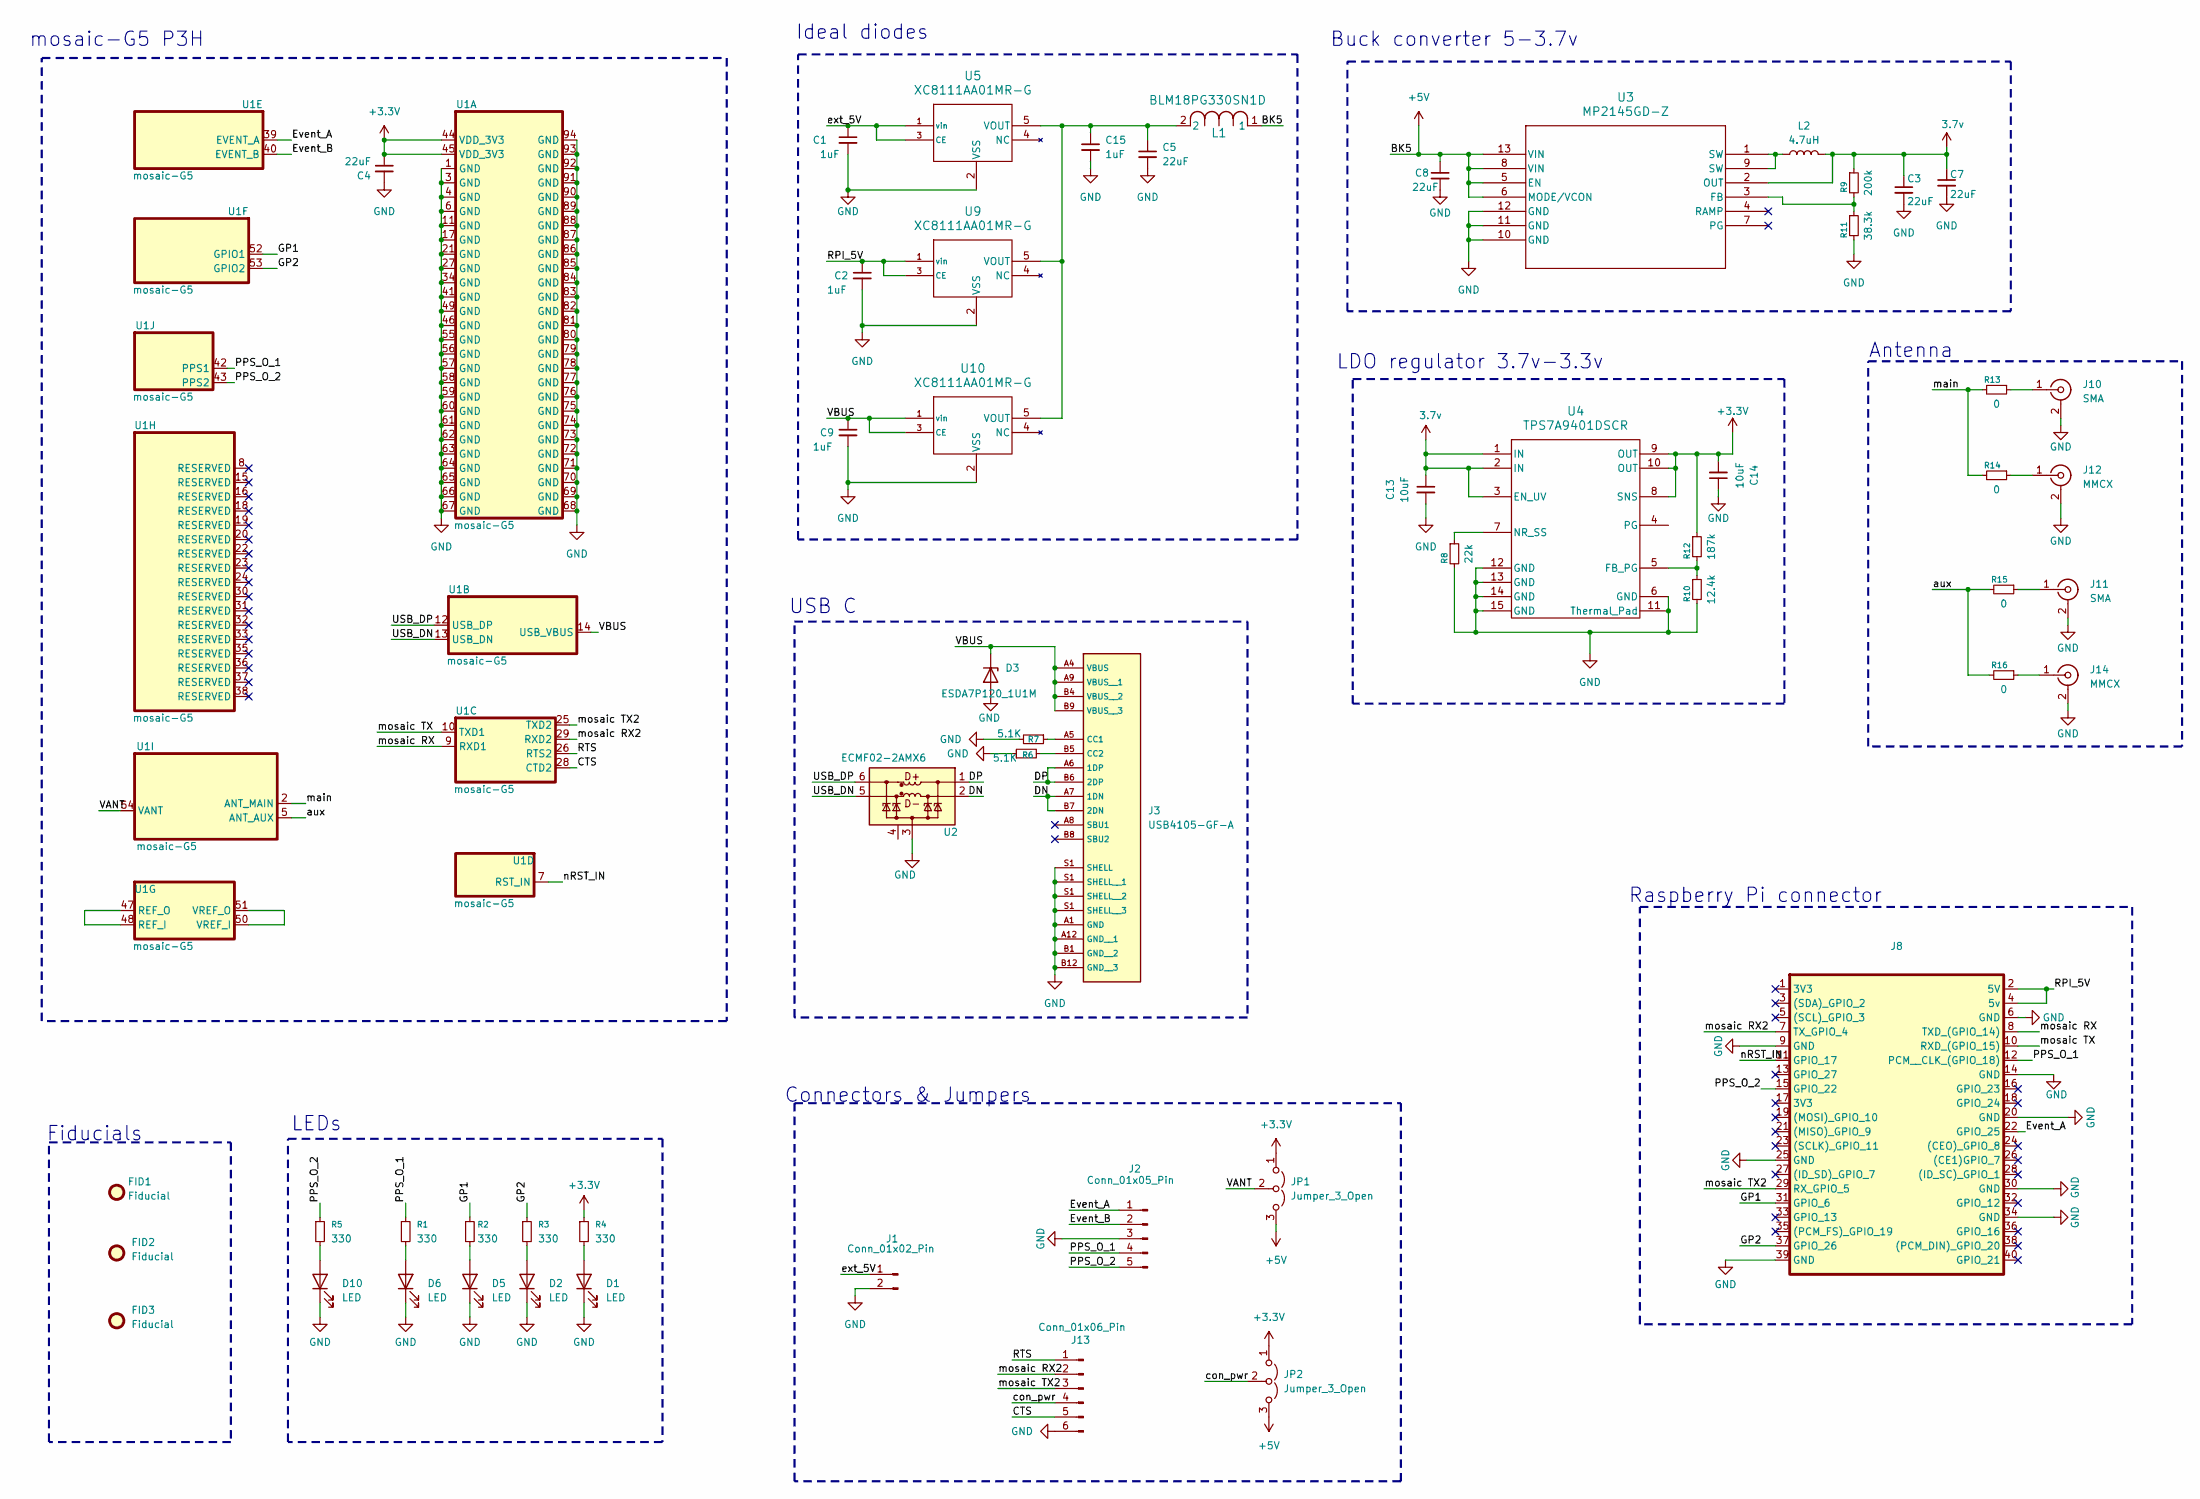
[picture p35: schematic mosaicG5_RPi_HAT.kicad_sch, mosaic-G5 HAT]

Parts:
C1, C2, C9, C15: 1uF; C_0603_1608Metric
C3, C5, C7, C8: 22uF; C_0805_2012Metric
C4: 22uF; CAPC1608X90
C13, C14: 10uF; CAPC1608X90
D1, D2, D5, D6, D10: LED; LED_0603_1608Metric
D3: ESDA7P120_1U1M; DIODE_ESDA7P120-1U1M_STM
FID1, FID2, FID3: Fiducial; Fiducial_1mm_Mask2mm
J1: Conn_01x02_Pin; PinHeader_1x02_P2.54mm_Vertical
J2: Conn_01x05_Pin; PinHeader_1x05_P2.54mm_Vertical
J3: USB4105-GF-A; USB_C_Receptacle_GCT_USB4105-xx-A_16P_TopMnt_Horizontal
J8: 2x20 2.54mm pitch
J10, J11: SMA; SMA_Amphenol_132134-16_Vertical
J12, J14: MMCX; SAMTEC_MMCX-J-P-H-ST-TH1
J13: Conn_01x06_Pin; PinHeader_1x06_P2.54mm_Vertical
JP1, JP2: Jumper_3_Open; PinHeader_1x03_P2.00mm_Vertical
L1: BLM18PG330SN1D; IND_BLM18_0603_MUR
L2: 4.7uH; IND_ASPI-4030S-4R7M-T
R1, R2, R3, R4, R5: 330; 0603 (1608metric)
R6, R7: 5.1K; 0603 (1608metric)
R8: 22k; 0603 (1608metric)
R9: 200k; 0603 (1608metric)
R10: 12.4k; 0603 (1608metric)
R11: 38.3k; 0603 (1608metric)
R12: 187k; 0603 (1608metric)
R13, R14, R15, R16: 0; R_0603_1608Metric
U1: mosaic-G5; LGA54_MOSAIC-MINI_SEP
U2: ECMF02-2AMX6; ST_UQFN-6L_1.5x1.7mm_P0.5mm
U3: MP2145GD-Z; QFN-12_MP2145_MNP
U4: TPS7A9401DSCR; DSC0010J-MFG
U5, U9, U10: XC8111AA01MR-G; SOT-25_TOR

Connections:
3.7v: C3.1, C7.1, C13.1, L2.2, R9.1, U3.2 (OUT), U4.1 (IN), U4.2 (IN), U4.3 (EN_UV)
+3.3V: C4.1, C14.2, JP1.1 (A), JP2.1 (A), R4.1, R12.1, U1.44 (VDD_3V3), U1.45 (VDD_3V3), U4.8 (SNS), U4.9 (OUT), U4.10 (OUT)
+5V: C8.1, JP1.3 (B), JP2.3 (B), L1.1, U3.5 (EN), U3.6 (MODE/VCON), U3.8 (VIN), U3.13 (VIN)
/CTS: J13.5, U1.28 (CTD2)
/DN: J3.A7 (1DN), J3.B7 (2DN), U2.2 (D-_in)
/DP: J3.A6 (1DP), J3.B6 (2DP), U2.1 (D+_in)
/Event_A: J2.1, J8.22 (GPIO_25), U1.39 (EVENT_A)
/Event_B: J2.2, U1.40 (EVENT_B)
/GP1: J8.31 (GPIO_6), R2.1, U1.52 (GPIO1)
/GP2: J8.37 (GPIO_26), R3.1, U1.53 (GPIO2)
/PPS_O_1: J2.4, J8.12 (PCM__CLK_(GPIO_18)), R1.1, U1.42 (PPS1)
/PPS_O_2: J2.5, J8.15 (GPIO_22), R5.1, U1.43 (PPS2)
/RPI_5V: C2.1, J8.2 (5V), J8.4 (5v), U9.1 (vin), U9.3 (CE)
/RTS: J13.1, U1.26 (RTS2)
/USB_DN: U1.13 (USB_DN), U2.5 (D-_out)
/USB_DP: U1.12 (USB_DP), U2.6 (D+_out)
/VANT: JP1.2 (C), U1.54 (VANT)
/VBUS: C9.1, D3.1 (K), J3.A4 (VBUS), J3.A9 (VBUS__1), J3.B4 (VBUS__2), J3.B9 (VBUS__3), U1.14 (USB_VBUS), U10.1 (vin), U10.3 (CE)
/aux: R15.2, R16.2, U1.5 (ANT_AUX)
/con_pwr: J13.4, JP2.2 (C)
/ext_5V: C1.1, J1.1, U5.1 (vin), U5.3 (CE)
/main: R13.2, R14.2, U1.2 (ANT_MAIN)
/mosaic RX: J8.8 (TXD_(GPIO_14)), U1.9 (RXD1)
/mosaic RX2: J8.7 (TX_GPIO_4), J13.2, U1.29 (RXD2)
/mosaic TX: J8.10 (RXD_(GPIO_15)), U1.10 (TXD1)
/mosaic TX2: J8.29 (RX_GPIO_5), J13.3, U1.25 (TXD2)
/nRST_IN: J8.11 (GPIO_17), U1.7 (RST_IN)
GND: C1.2, C2.2, C3.2, C4.2, C5.2, C7.2, C8.2, C9.2, C13.2, C14.1, C15.2, D1.1 (K), D2.1 (K), D3.2 (A), D5.1 (K), D6.1 (K), D10.1 (K), J1.2, J2.3, J3.A1 (GND), J3.A12 (GND__1), J3.B1 (GND__2), J3.B12 (GND__3), J3.S1 (SHELL__2), J8.6 (GND), J8.9 (GND), J8.14 (GND), J8.20 (GND), J8.25 (GND), J8.30 (GND), J8.34 (GND), J8.39 (GND), J10.2 (Ext), J11.2 (Ext), J12.2 (Ext), J13.6, J14.2 (Ext), R6.1, R7.2, R8.2, R10.2, R11.2, U1.1 (GND), U1.3 (GND), U1.4 (GND), U1.6 (GND), U1.11 (GND), U1.17 (GND), U1.21 (GND), U1.27 (GND), U1.34 (GND), U1.41 (GND), U1.46 (GND), U1.49 (GND), U1.55 (GND), U1.56 (GND), U1.57 (GND), U1.58 (GND), U1.59 (GND), U1.60 (GND), U1.61 (GND), U1.62 (GND), U1.63 (GND), U1.64 (GND), U1.65 (GND), U1.66 (GND), U1.67 (GND), U1.68 (GND), U1.69 (GND), U1.70 (GND), U1.71 (GND), U1.72 (GND), U1.73 (GND), U1.74 (GND), U1.75 (GND), U1.76 (GND), U1.77 (GND), U1.78 (GND), U1.79 (GND), U1.80 (GND), U1.81 (GND), U1.82 (GND), U1.83 (GND), U1.84 (GND), U1.85 (GND), U1.86 (GND), U1.87 (GND), U1.88 (GND), U1.89 (GND), U1.90 (GND), U1.91 (GND), U1.92 (GND), U1.93 (GND), U1.94 (GND), U2.3 (GND), U3.10 (GND), U3.11 (GND), U3.12 (GND), U4.6 (GND), U4.11 (Thermal_Pad), U4.12 (GND), U4.13 (GND), U4.14 (GND), U4.15 (GND), U5.2 (VSS), U9.2 (VSS), U10.2 (VSS)
unnamed: D1.2 (A), R4.2
unnamed: D2.2 (A), R3.2
unnamed: D5.2 (A), R2.2
unnamed: D6.2 (A), R1.2
unnamed: D10.2 (A), R5.2
unnamed: J3.A5 (CC1), R7.1
unnamed: J3.B5 (CC2), R6.2
unnamed: J10.1 (In), R13.1
unnamed: J11.1 (In), R15.1
unnamed: J12.1 (In), R14.1
unnamed: J14.1 (In), R16.1
unnamed: L2.1, U3.1 (SW), U3.9 (SW)
unnamed: U1.47 (REF_O), U1.48 (REF_I)
unnamed: U1.50 (VREF_I), U1.51 (VREF_O)
unnamed: R9.2, R11.1, U3.3 (FB)
unnamed: R10.1, R12.2, U4.5 (FB_PG)
unnamed: R8.1, U4.7 (NR_SS)
unnamed: C5.1, C15.1, L1.2, U5.5 (VOUT), U9.5 (VOUT), U10.5 (VOUT)

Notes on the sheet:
Fiducials
Connectors & Jumpers
Ideal diodes
mosaic-G5 P3H
Buck converter 5-3.7v
USB C
LDO regulator 3.7v-3.3v
Antenna
Raspberry Pi connector
LEDs

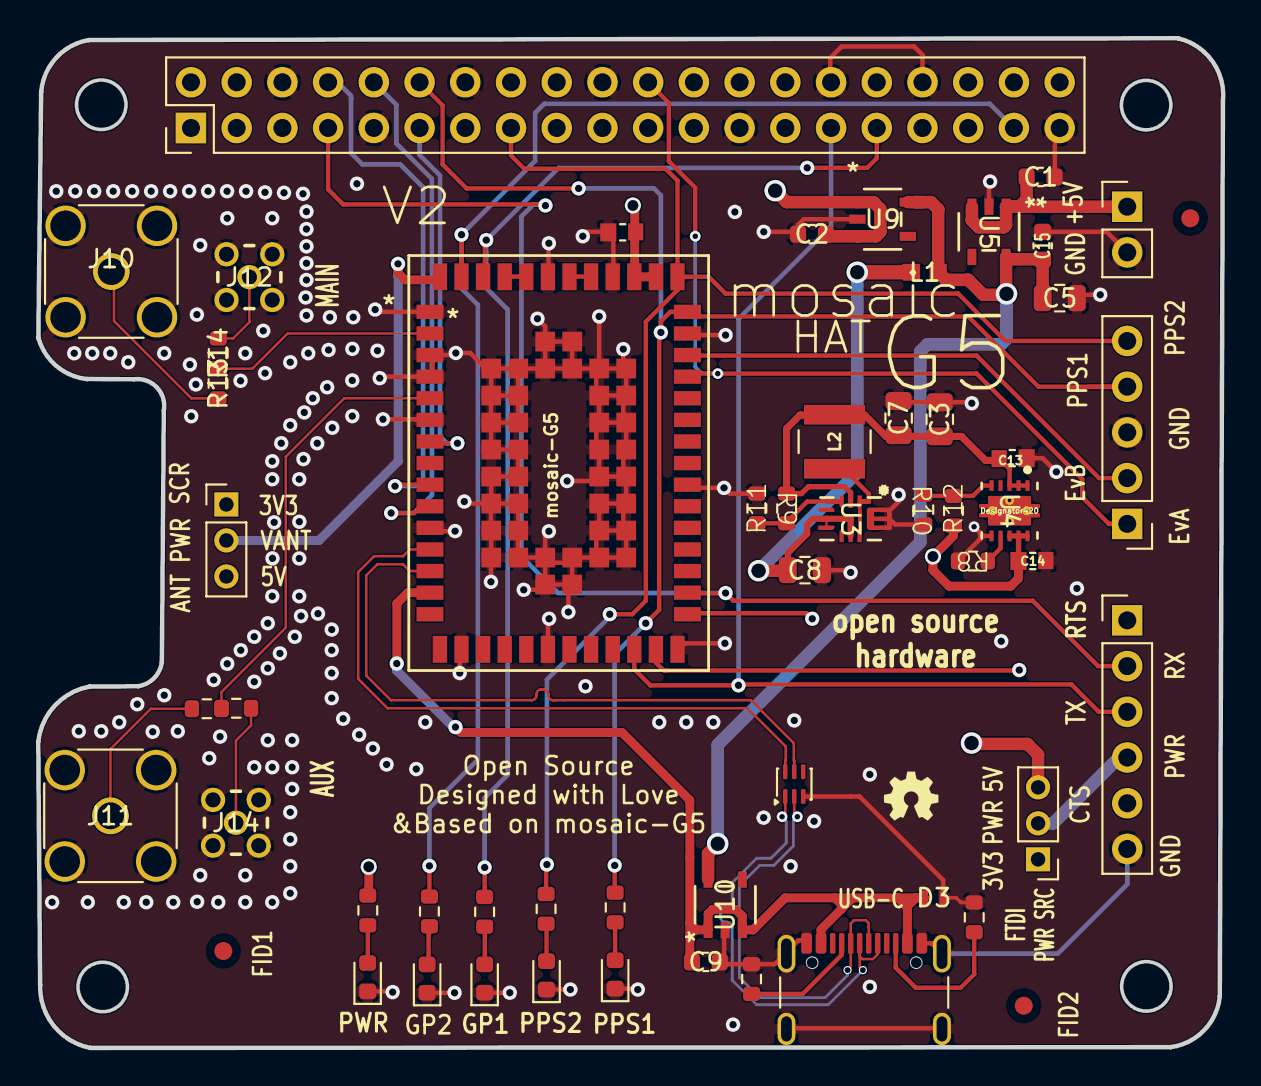
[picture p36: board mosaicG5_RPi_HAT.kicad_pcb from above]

Board: 4 copper layers, 65.8 x 56.1 mm, 56 parts (0 on the bottom side), 46 nets.

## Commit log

2026-07-03 First upload
    First upload to the repository
    [mosaicG5_RPi_HAT.kicad_pcb, mosaicG5_RPi_HAT.kicad_sch]
2026-08-09 logo schematic
    [mosaicG5_RPi_HAT.kicad_sch]
2026-08-19 mosaicG5 HAT V2
    [BOM P3H_V2.xlsx, BOM.xlsx, mosaicG5_RPi_HAT.kicad_pcb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]
